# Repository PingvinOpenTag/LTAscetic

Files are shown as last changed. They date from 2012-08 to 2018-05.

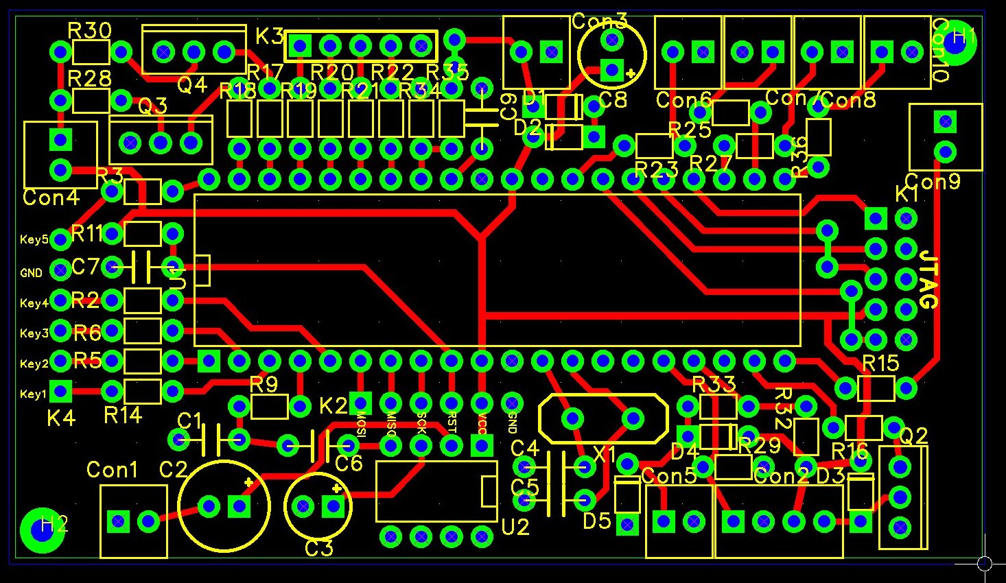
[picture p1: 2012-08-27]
release_2(LCD,Joystck,TouchMemory,Reload,Antichiter,IrPowerControl,BattaryControl)/hardware/pcb/layout.jpeg

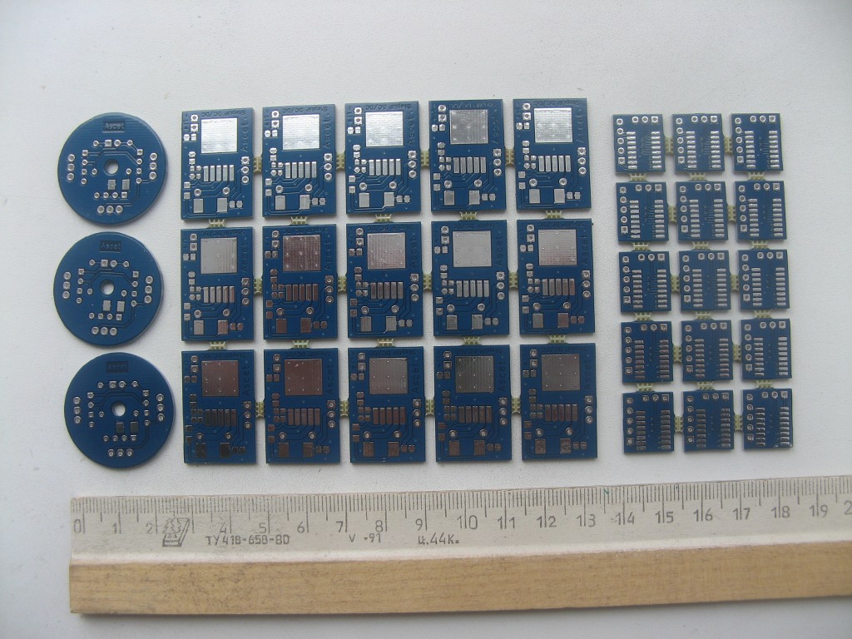
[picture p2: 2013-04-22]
release_3_1(SMD,fix_flesh_led_bag,firmware_up_to_56000Hz_IR_F0)/hardware/pcb/ir_sensor&step_up_dcdc&rs232_modul_pcb.jpeg

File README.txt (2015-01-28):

This is an open lasertag project.

In the directory "source" is the firmware source code
Copy the directory "/source/LTAscetic_Atmega32" on hard disk.
Open the file "X:/LTAsceric_Atmega32/LTAscetic_Atmega32.aps" in the program "AVR-Studio 4.16" (or 4.17, 4.18)
Сan work! :-)

!!!DO NOT USE 4.19 VERSION!!!

Just need to install the compiller WinAVR.

Program to configure the "Ascetic" and upload sounds.

http://sourceforge.net/projects/ascetconfigurat/files/Ascet-configurator/01_2013/

NEW!!!

http://sourceforge.net/projects/ascetconfigurat/files/Ascet-configurator/Qt5_version/02_10_2014/Configurator_and_libs_10_sounds.zip/download

Android port (Qt version)
http://sourceforge.net/projects/ascetconfigurat/files/Ascet-configurator/Qt5_Android_version/

PonyProg
serial device programmer

http://www.lancos.com/prog.html

PC software to use bootloader

http://download.chip45.com/chip45boot2_GUI_V1.13.zip

Part list for de.mouser (Use at your own Risk and please check !)

LTA Motherboard (3.1)
http://www.mouser.com/ProjectManager/ProjectDetail.aspx?AccessID=8740157a16

LTA Ir Sensor (3.1)

http://www.mouser.com/ProjectManager/ProjectDetail.aspx?AccessID=37c73c7856

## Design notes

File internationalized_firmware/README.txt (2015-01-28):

In the directory "source" is the firmware source code
Copy the directory "/source/" on hard disk.
Open the file "X:/source/LTAscetic_Atmega32.aps" in the program "AVR-Studio 4.16" (or 4.17, 4.18)
Сan work! :-)

!!!DO NOT USE 4.19 VERSION!!!

Just need to install the compiller WinAVR.

To compile the firmware with support for English, in the file ltag_ascetic.h define the macro LANGUAGE as follows:
#define LANGUAGE EN

if you want the message on the screen LСD and parameter names were in Russian, define the macro LANGUAGE as follows:

#define LANGUAGE RU

Program to configure the "Ascetic" and upload sounds.

http://sourceforge.net/projects/ascetconfigurat/files/Ascet-configurator/01_2013/

NEW!!!

http://sourceforge.net/projects/ascetconfigurat/files/Ascet-configurator/Qt5_version/02_10_2014/Configurator_and_libs_10_sounds.zip/download

PonyProg
serial device programmer

http://www.lancos.com/prog.html

PC software to use bootloader

http://download.chip45.com/chip45boot2_GUI_V1.13.zip

Part list for de.mouser (Use at your own Risk and please check !)

LTA Motherboard (3.1)
http://www.mouser.com/ProjectManager/ProjectDetail.aspx?AccessID=8740157a16

LTA Ir Sensor (3.1)

http://www.mouser.com/ProjectManager/ProjectDetail.aspx?AccessID=37c73c7856

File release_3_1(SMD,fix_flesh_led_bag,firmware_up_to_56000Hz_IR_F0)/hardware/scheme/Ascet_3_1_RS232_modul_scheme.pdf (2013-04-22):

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

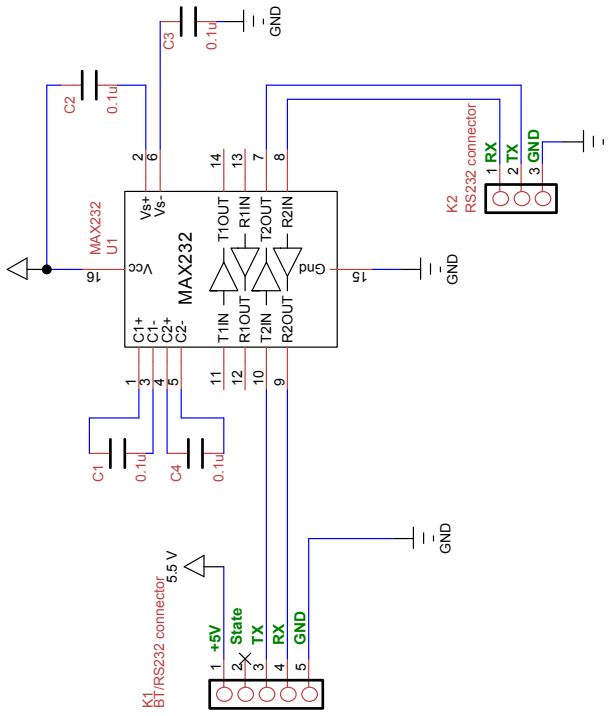
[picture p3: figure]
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

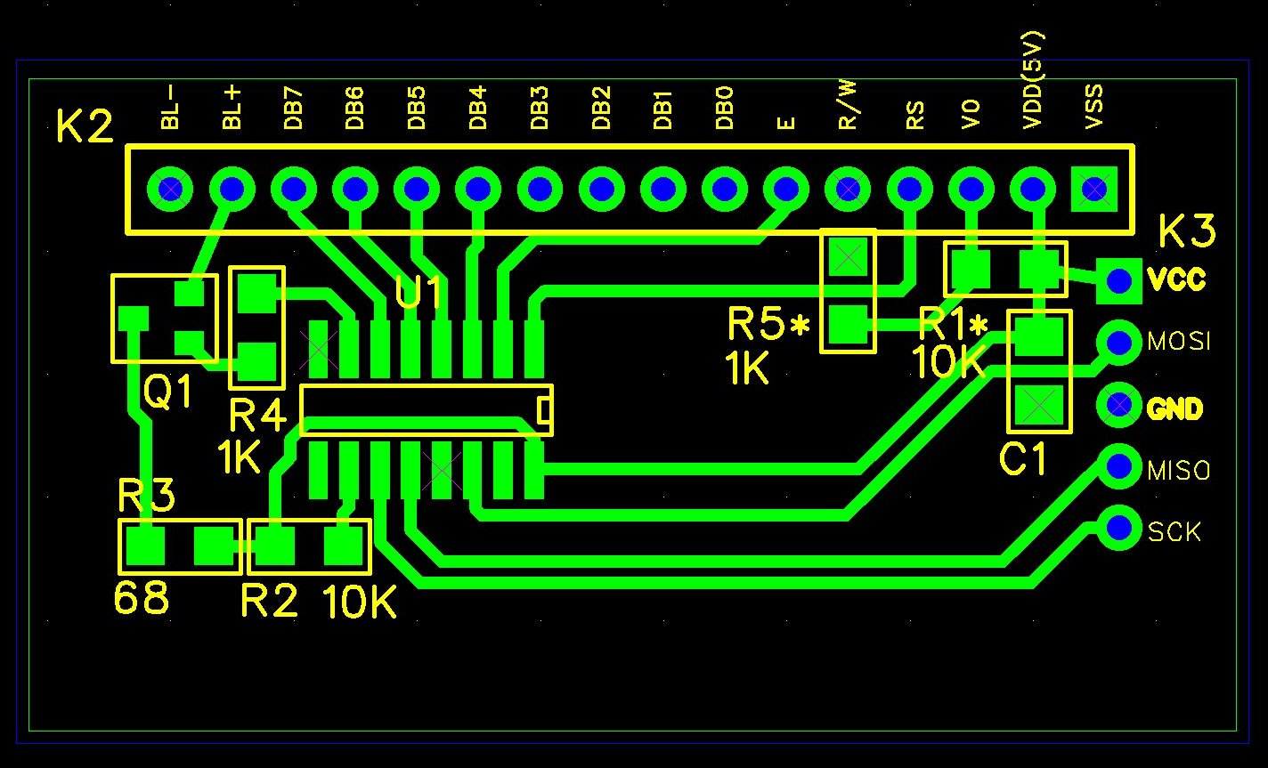
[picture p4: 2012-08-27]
release_2(LCD,Joystck,TouchMemory,Reload,Antichiter,IrPowerControl,BattaryControl)/hardware/pcb/lcd_shield_smd_layout.jpeg

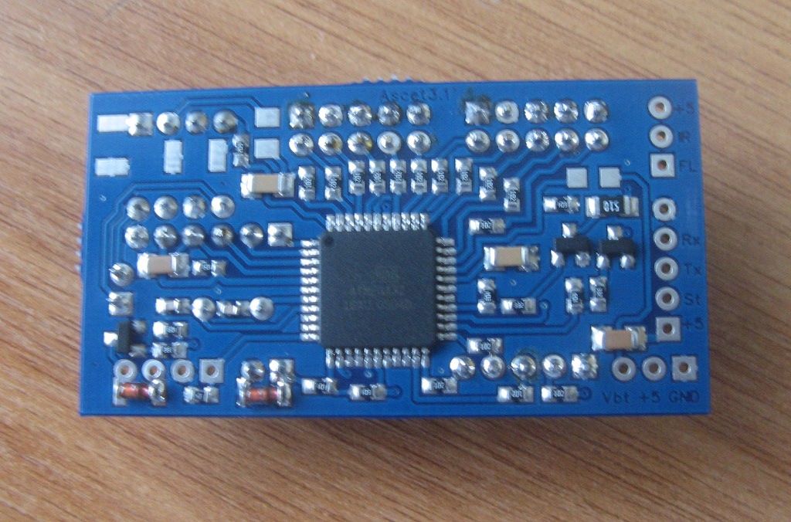
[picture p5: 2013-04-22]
release_3_1(SMD,fix_flesh_led_bag,firmware_up_to_56000Hz_IR_F0)/hardware/ascet_3_1_top.jpeg

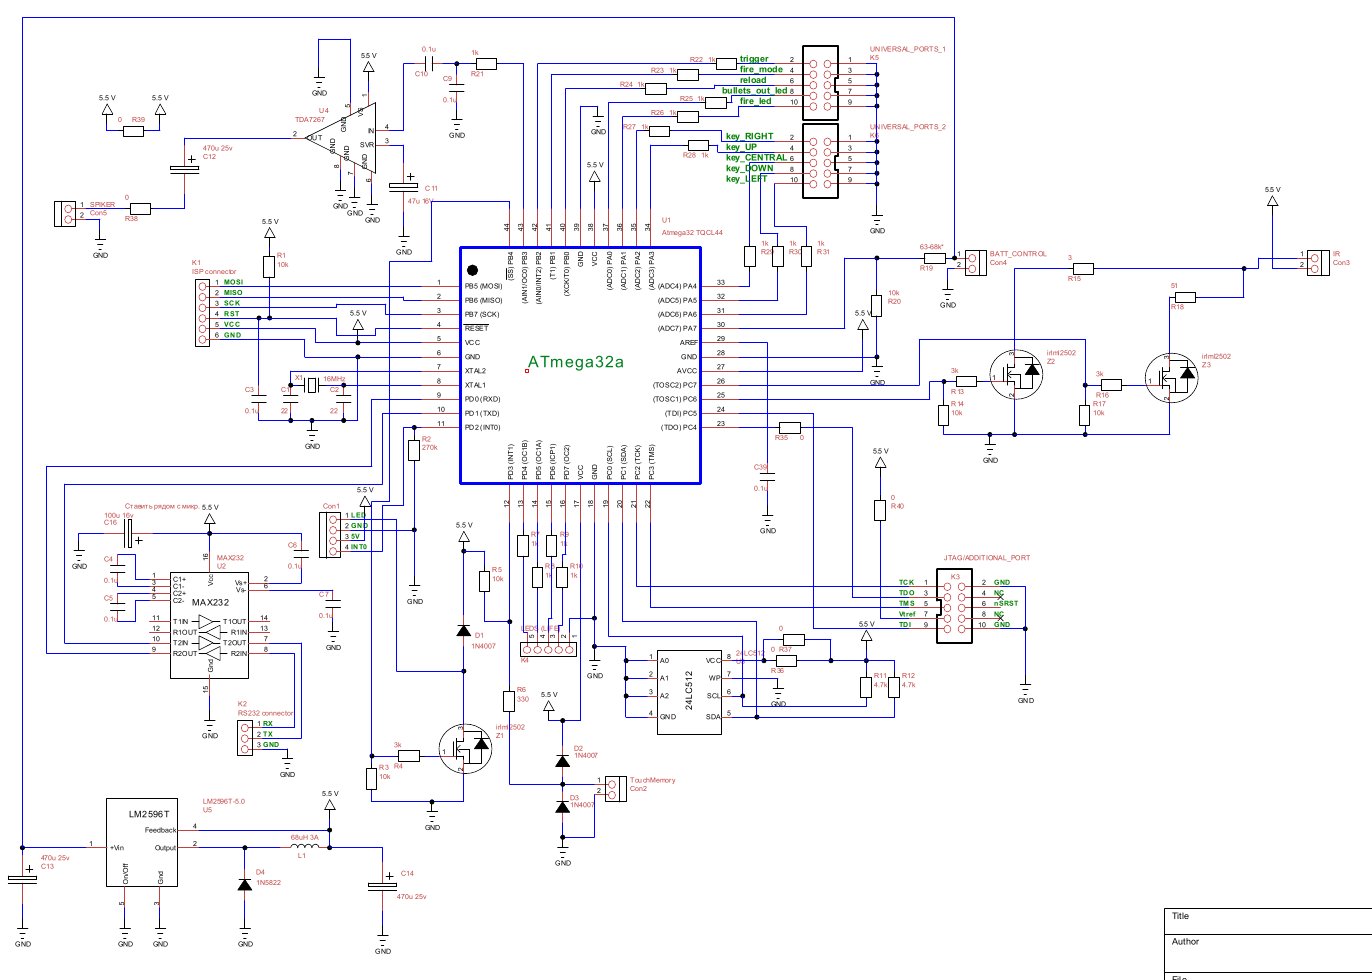
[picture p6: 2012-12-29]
release_3(all_thet_is_in_the_release_2,extern_EEPROM_RS232_BOOTLOADER)/hardware/scheme/Ascetic_3_scheme.jpg

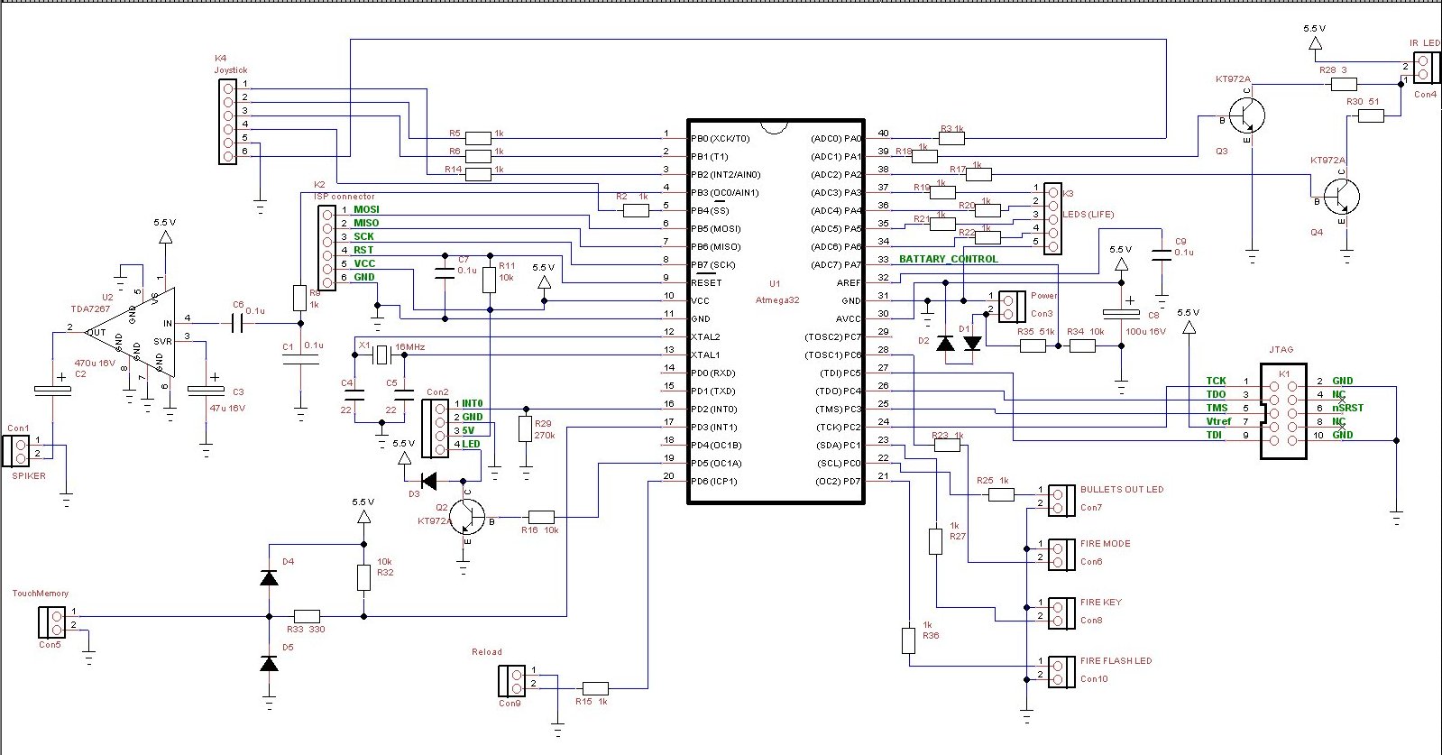
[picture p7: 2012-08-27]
release_2(LCD,Joystck,TouchMemory,Reload,Antichiter,IrPowerControl,BattaryControl)/hardware/scheme/scheme.jpeg

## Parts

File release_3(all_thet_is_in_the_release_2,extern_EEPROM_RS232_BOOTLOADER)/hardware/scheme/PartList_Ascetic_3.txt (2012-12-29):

====+  Parts List   +====

R35,R36,R37,R38,R39,R40       6   0,Resistor,1206
C16                           1   100u 16v,Electrolitic Capacitor
R1,R14,R17,R20,R5             5   10k,Resistor,0603
R3                            1   10k,Resistor,1206
D1,D2,D3                      3   1N4007
D4                            1   1N5822
R21,R22,R23,R24,R25,R26,R27,
R28,R29,R30,R31              11   1k,Resistor,0603
R10,R7,R8,R9                  4   1k,Resistor,1206
U3                            1   24LC512,512 Кбит (64К x 8) SEEPROM, I2C 400 КГц, 2.5- 5.5 V, SOIC-8
R2                            1   270k,Resistor,1206
R15                           1   3,Resistor,1206
R6                            1   330,Resistor,1206
R13,R16                       2   3k,Resistor,0603
R4                            1   3k,Resistor,1206
R11,R12                       2   4.7k,Resistor,1206
C12,C13,C14                   3   470u 25v,Electrolitic Capacitor
C11                           1   47u 16V,Electrolitic Capacitor
R18                           1   51,Resistor,1206
R19                           1   63-68k*,Resistor,1206
U1                            1   Atmega32,TQFP44
Con4                          1   BATT_CONTROL,New symbol,Conn2
C3,C39,C4,C5,C6,C7,C9,C10     8   0.1u,Ceramic Capacitor,1206
C1,C2                         2   22,Ceramic Capacitor,1206
K1,                           1   PLS-40 (6 pin), 2,54мм
K3,K5,K6                      3   PLD80 (2x5 pin), 2.54мм
L1                            1   68uH 3A,INDUCTOR
K4                            1   PLS-40 (5 pin), 2,54мм
U5                            1   LM2596T-5.0,Step-Down DC/DC convertor 5V 3A, TO-220-5
U2                            1   MAX232,Dual Full-Duplex RS232 Transceiver,SOIC-16
K2                            1   PLS-40 (3 pin), 2,54мм
U4                            1   TDA7267,DIP8
X1                            1   16MHz,Crystal Oscillator,
Z1,Z2,Z3                      3   irlml2502,SOT23
Con2,Con3,Con4,Con5           4   DG308-2.5-02P-14-00A(H)
Con1                          1   2xDG308-2.5-02P-14-00A(H)

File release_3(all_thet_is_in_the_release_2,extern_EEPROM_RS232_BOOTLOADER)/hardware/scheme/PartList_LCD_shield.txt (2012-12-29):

====+  Parts List for LTAscetic\release_3(all_thet_is_in_the_release_2,extern_EEPROM_RS232_BOOTLOADER)\hardware\scheme\TinyCAD_files\LCD_SMD_SHIELD.dsn  +====

R3                            1   68,Resistor,1206
R5*,R4                        2   1.1k,Resistor,1206
R1*,R2                        2   10k,Resistor,1206
U1                            1   74HC595D,S016
Q1                            1   BC847C,SOT-23
C1                            1   0.1u,Ceramic Capacitor,1206
K3                            1   PLS-40 (5 pin), 2,54мм
K2                            1   PLS-40 (16 pin), 2,54мм

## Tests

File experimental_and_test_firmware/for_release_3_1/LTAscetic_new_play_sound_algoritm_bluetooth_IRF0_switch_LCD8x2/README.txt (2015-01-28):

In this version of the firmware, there are important changes and additions.

Firmware can work with both wired bandanna, so it is with wireless Bluetooth bandana, and at the same time with two bandanas (bluetooth and wired).
Anticheat controls both zones, therefore,

IMPORTANT !!!
If you plan to use only wired bandanna, it is necessary to conclude pin STATE on the Bluetooth-connector to connect through a resistor 270K to ground.
Otherwise anticheat will not work correctly!
If you are difficult to solder a resistor, there is another way - correct file isr.с : in function ISR(TIMER1_COMPA_vect) {...} get the line to read

if ((! (TSOP_IN & TSOP_PIN)) && (! (BT_STATE_IN & BT_STATE_PIN))) // if the input INT0 low level and there is no Bluetooth connection

and correct it so

if ((! (TSOP_IN & TSOP_PIN)) / * && (! (BT_STATE_IN & BT_STATE_PIN)) * /) // if the input INT0 low level

Rebuild the project. 
The new firmware file with the extension .hex will be in a subdirectory "defalt" of the project directory.

Rewritten algorithm play audio files.
In this firmware sound files are reproduced through the interruption, and not in the main program loop.
Therefore, the main loop of the program keeps track of game events at the time, when you hear the sound.
Therefore, it became possible to process all the hits, that happened during playback  "injured sound".
But to give the player a chance to survive when he is being fired gunfire, put such a thing as "time invulnerability."
During this time, after the hit, the player invulnerable, all hit ignored.
Duration of invulnerability is adjustable from 0.5 seconds to 3 seconds.

In the settings now made and the carrier frequency of the IR signal - 36 or 56 kHz.

You can also adjust the rate when shooting in auto mode.

Firmware understands the IR RC command "Start Game" and "kill the player" and commands to change the colors of the team.
You can use the remote control "ascet-pult".
http://github.com/PingvinOpenTag/LTAscetic/tree/master/Ascet_pult_3_1
But before using it must be initialized after the firmware download.
Command to initialize on the menu.

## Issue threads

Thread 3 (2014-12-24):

Feature request: Englisch Translation

gamecompiler, 2014-12-24:
Hi, i and my friends use the LTAscetic project in Germany very much.
Its nice, and works well.
But the problem is, the LCD menu and the LTAscetic Configurator.
Only one in my team speaks the russian language.
Only he can use the Configurator.

This is a feature request(?): Please Translate the menu and the Configurator to English.

Thank you in Advance.

Tipp: I added a current regulator for the LED on the pcb to save power. Works well.

PingvinOpenTag, 2015-01-01:
Generating SSH keys
https://help.github.com/articles/generating-ssh-keys/
and send me the key.
I'll add it to the server, and you will have access, if I understand correctly the server.

 >> Your yadi.sk version or release 3_1 ?

Yes.

gamecompiler, 2015-01-01:
Oh, sorry my handy dont showed me the rest of the e-mail....
Id send it to your github e-mail -> ms_present_god@mail.ru
But i will resend it to your other e-mail.

gamecompiler, 2015-01-04:
Sorry, I have not started yet, I have huge headaches.
I'll get back to you if I feel good again.

Sorry.

gamecompiler, 2015-01-05:
Im back, id checked  insensitiveclod´s code on https://github.com/insensitiveclod/LTAscetic.
And i did not found any code difference.
It took me nearly 7 hours for the review....
The English Translation of his work is almost complete and has a good quality. Please put his code in the main repo if you also think his translation is ok.

insensitiveclod, 2015-01-07:
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

Wow:)

Such honor *bow*

The code compiles exactly the same as the version I used before
translation. It's only comments that got translated, prettified and a
bit streamlined.

I will pick up the work of making it 'even nicer' soon, by doing
code-cleanup a bit.
First i will look at the configurator + translation.

--
 Arnd

gamecompiler, 2015-01-07:
Awesome nice. I cant await to hear when you are ready. :)I currently try to find a translation trick for the Firmware which is better then global variables. Maybe we can store Kind of Language files in the EEPROM.(Sorry for those bad Spelling, German T9 in my mobile phone)-------- Originalnachricht --------Betreff: Re: [LTAscetic] Feature request: Englisch Translation (#3)Von: insensitiveclod An: PingvinOpenTag/LTAscetic Cc: Jason On 01/07/2015 02:00 PM, Pingvin wrote:
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

Wow:)

Such honor *bow*

The code compiles exactly the same as the version I used before
translation. It's only comments that got translated, prettified and a
bit streamlined.

I will pick up the work of making it 'even nicer' soon, by doing
code-cleanup a bit.
First i will look at the configurator + translation.

--
 Arnd

—Reply to this email directly or view it on GitHub.

PingvinOpenTag, 2015-01-07:
I can not add your ssh-key.
I do not know why, but there is an error.
Send it as an archive, try more.

gamecompiler, 2015-01-12:
Id see you added sth you call Anti-Cheat.
Who does this Anti-Cheat system work ?

Thanks in Advance.

PingvinOpenTag, 2015-01-13:
Anti-cheat does not allow the player to disconnect bandana during the game on or off Bluetooth bandanna.
That it can not be Duncan Macleod ;-)

gamecompiler, 2015-01-13:
I cant find the TDA7052 on Mouser as DIP.
We may need another Distributer for our parts.
Or we change the PCB, to let the SMD Version fit.

Or could i use a similiar IC ?
Id found the NJM386 IC.
Its similiar, has more features, we could change the volume over a gain pin.
And it has output power of 1 Watts.

http://www.mouser.com/ds/2/294/NJM386_E-232003.pdf

I would prefer to use mouser because mouser ships worldwide and is very cheap in conclusion to my known distributors.

PingvinOpenTag, 2015-01-16:
Began to correct the source firmware for multi-language support.
I use this method, in header file

#define EN 0
#define RU 1

#define LANGUAGE EN

in C file

#if LANGUAGE == RU
lcd_puts("Ключ ТМ");
#elif LANGUAGE == EN
lcd_puts("ТМ key");
#endif
lcd_gotoxy(0, 1);
#if LANGUAGE == RU
lcd_puts("записан!");
#elif LANGUAGE == EN
lcd_puts("recorded");
#endif

Teie, 2015-05-14:
Hi Pingvin, I'm Theuer from Brazil.
 GREAT JOB you made here!
I'm doing your project at protonboard, I tried open the ".c" files at maaaany softwares because my idea was to do "copy" Rusian COMMENTS and "paste" at Google Translator, but the comments not appears in Cyrillic. All comments appears like this: "//«‡ÔËÒ¸ ·‡ÈÚ‡ ‚ ÏÓ‰ÛÎ¸ Ô‡ÏˇÚË EEPROM"
 Do you know why?
 Others thing, I did not understand what it is for the EEPROM memory. Is it for Score? (Please say yes!) :)

 Sorry for terrible english, and congratulations for your hard work!
 See you, Theuer.

gamecompiler, 2015-05-15:
The Translation is already (almost) done, please try to read the issues first before you comment.
https://github.com/PingvinOpenTag/LTAscetic/tree/master/internationalized_firmware

Im not sure for what the EEPROM memory is for.
If i remember correct, it contains the playerid and settings like ammo, battery settings (Max and min values when the battery is full or empty e.t.c), health, damage rate....

If im correct there is no score feature, but if you like to add it, please feel free to share your code.

If you have more question, please feel free to ask ;D
Sorry for my english.

Teie, 2015-05-15:
I read the issues, but I had understood that the partial translation was in "internationalized_firmware" and when I opened, everything I saw was "//«‡ÔËÒ¸ ·‡ÈÚ‡ ‚ ÏÓ‰ÛÎ". Now I opened "intensitivecloud" and I found it all translated.

 Yes, my goal is to write score feature. My current system is MicroMT, and I'm dropping it because they lack the Score feature.
 My big question about ASCETIC was it can handle or not the Score feature, and today Pingvin answer:
 "Yes, of course - it is able to."
 Challenge accepted! :)

PingvinOpenTag, 2015-06-13:
GitHab why the substitute encoding. Try to download and unpack the archive. Yes, we have an internal controller eeprom little used. There's plenty of space to save the recorded hits.

Closed 2015-05-15.

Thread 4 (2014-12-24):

Pleases add a part list

gamecompiler, 2014-12-24:
Id made a part list for the LTAscetic 3.1 release.

Part list for de.mouser (Use at your own Risk and please check !)
If checked please add it to the Readme.md

LTA Motherboard (3.1)
http://www.mouser.com/ProjectManager/ProjectDetail.aspx?AccessID=8740157a16

LTA Ir Sensor	(3.1)

http://www.mouser.com/ProjectManager/ProjectDetail.aspx?AccessID=37c73c7856

PingvinOpenTag, 2015-01-05:
Ascet-configurator port from PC to Android
http://www.youtube.com/watch?v=n5ikXYz3mhE

Upload sounds use configurator on Android
http://www.youtube.com/watch?v=lW9ozMrs18M&feature=youtu.be

gamecompiler, 2015-01-05:
Could we use the NJM386 IC ?
Its avaible as DIP.
Or we use the SMD edition of the NJM386 IC.
You would need to change the pcb if we use the SMD edition.

What should we do ?

gamecompiler, 2015-01-13:
One Question, about the LCD-universal-Modul.
What data is owned by the Q1-BC847 and U1-MC74HC595AD (I only need the case type).
I will publish some more part lists if im ready.

Could you please send me a fix of the Bluetooth modul pcb DIPTrace_files ? I cant read the DIPTrace_files without problems. Part 1-2, i see something dont readable for me, my pc cant decode the russian language, i think.
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

Thanks in Advance

PingvinOpenTag, 2015-01-14:
And where do NJM386 IC?
It's a completely different chip, as I understand it.
Or it is a complete analog TDA7052A?

Сhange the pcb  can by anything, a matter of expediency.
I have no such need.

PingvinOpenTag, 2015-01-14:
BC847 has the same body as irlml2502  - SOT-23 (SMD).
74HC595D - SOIC-16 (SMD)

gamecompiler, 2015-01-14:
Id have problems ordering the Matherboard pcbs, could you export the gerber files as GBR files please ?

Freepcb wont let me do that.
Thanks in Advance.

PingvinOpenTag, 2015-01-14:
Complexity of translation.
I do not understand - from what program you want to export Gerber files?
And what of the PCB?

PingvinOpenTag, 2015-01-14:
I'd like to know more about your hardware.
Where to order the production of printed circuit boards?
Which configuration using ascetic?
Few photos, video ...
Could bring some joy to the old man?

gamecompiler, 2015-01-14:
Id ordered my pcbs at www.dirtypcbs.com.
They are not as dirty as id thought.
I will post pictures if id received them, and id built them.
Yes i could send some joy to the old man :).
But first i need to receive them.

I have following problems currently ordering the pcbs.

I need following types of data

Gerber file extension 	Layer
GTO 	Top Silkscreen (text)
GTS 	Top Soldermask (the 'green' stuff)
GTL 	Top Copper (conducting layer)
GBL 	Bottom Copper
GBS 	Bottom Soldermask
GBO 	Bottom Silkscreen
GML/GKO/GBR* 	Board Outline*
TXT 	Routing and Drill (the holes and slots)

First attempt was to convert the existing files to the needed files.
Id fail....

At this moment i redesign the Board in eagle; They also can use brd files.
The problem is that i will need to have this files in this night.
I think i will have a long night....

gamecompiler, 2015-01-14:
WARNING: Id found a lot of Erros, in the mouser part-liste.
Mouser did deledt some product pages, im not sure why....
Please DO NOT USE IT....
I need to fix that problems....
So many problems this night.... ARGH

gamecompiler, 2015-01-14:
Id redesigned the IR_Sensor in Eagle, i think this new design looks better.
And its a little bit cheaper to produce.
http://www.file-upload.net/download-10147101/export_IR_Sensor.zip.html

gamecompiler, 2015-01-15:
UPDATE: My new redesigned layout:
Do you think its ok ?
Sorry im under stress....

IR_SENSOR

http://dirtypcbs.com/order_images/13d093c9d5b35f3950eb14d471d986d7-4080_bottom.png
http://dirtypcbs.com/order_images/13d093c9d5b35f3950eb14d471d986d7-4080_top.png

LCD_UNI....

http://dirtypcbs.com/order_images/13d093c9d5b35f3950eb14d471d986d7-4081_bottom.png
http://dirtypcbs.com/order_images/13d093c9d5b35f3950eb14d471d986d7-4081_top.png

PingvinOpenTag, 2015-01-15:
FreePCB perfectly formed Gerber files!
Only for some reason he gives them another extension.
Do not worry, you can rename.
Gerber files are in the repository.
I did not do the Silks only
I did not do the inscriptions only Copper, Soldermask, Board Outline, Drill layers.

PingvinOpenTag, 2015-01-15:
What you do not like my version of the LCD module?
http://raw.githubusercontent.com/PingvinOpenTag/LTAscetic/master/release_2%28LCD,Joystck,TouchMemory,Reload,Antichiter,IrPowerControl,BattaryControl%29/hardware/pcb/lcd_shield_smd_layout.jpeg

PingvinOpenTag, 2015-01-15:
Blame !!!
Gerber files LCD module is not in the repository 2 release!
I mast to fix it!

I have Gerber files on all PCB that are laid out in the repository!

PingvinOpenTag, 2015-01-15:
GERBER for LCD module release 2.
https://yadi.sk/d/NVg_-IIMdykhL

PingvinOpenTag, 2015-01-15:
Why do you have such thin tracks on the boards?

gamecompiler, 2015-01-15:
Thanks for your gerber Files.
And a HUGE thanks for the tipp to rename the files.
I will try it out now.
I like your LCD_Shield Design ! But id thought i have to redesign everything in eagle.
Id also started last night to redesign the Matherboard in eagle.
I like more my IR_Sensor Design. I think it will be easier to wire to the head and shoulders.

Why such thin tracks ?; I do not know, id thought it will be enough thick. There is no really reason why id maked it as thin as it is.

gamecompiler, 2015-01-15:
Worked. Thank you !
Suuuch much thanks !

Cant await when they become shipped ;D

PingvinOpenTag, 2015-01-15:
So you do not have workers pay an "Аscetic"?
But you wrote that using them together with your friends!
What I do not understand ...

gamecompiler, 2015-01-15:
Now i do not understand you.
But i think I know what you do not understand.

I let my pcbs produce by www.dirtypcbs.com.
I and my friends already use LTAscetic, but dirty built on Breadboards.
So id decided to produce everything as pcb.
Yes my friends pay money to me, i build the Lasertag weapons for them.

Im not sure what you did not understand. Sorry.
And what do you mean with workers ?
Workes pay an Ascetic ?!? Huh ?

Im a Student in the 11. class.
Just to say it. I do not own a company.

PingvinOpenTag, 2015-01-15:
It's all  translator!
"рабочая плата" (works PCB) not "заработная плата" (Wages)

I wrote verbatim "Так у Вас нет рабочих плат Аскета? "
And the correct translation would be
"So you do not have workers PCB an ascetic?"
Here's a lesson in linguistics turned out!

gamecompiler, 2015-01-15:
I think we should create a Scoring Utility for Android.
I think it would be awesome to see Scores on a huge TV Screen using a Android TV Settop-Box.

Could you share your Code of your Android-APP ?
And could you make a Documentary how the Bluetooth/Serial commands work (A list would be enough) ?

Could i add lives or ammo to somebody over Bluetooth ?
Could we add a gamemode type like Capture of the Hill or Capture the Flag ?
First the code should be cleaned up ! What happend with Intensitiveclod ?
Is he/she already ready ? Did he/she already started ?

gamecompiler, 2015-01-15:
Part list updated

B45196H2476M309 is now knowed as T491C476M010AT.
That was the problem
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
gamecompiler, 2015-01-15:
Sorry, but i dont understand you

-->
Want, I will inquire the account on a partially assembled motherboard?
Can and sensors, but I ordered a kit, with collating chit will be more expensive, but Mogi and learn about them.
<--

PingvinOpenTag, 2015-01-15:
I can ask to me to issue an invoice for the production of printed circuit boards.
For comparison.

gamecompiler, 2015-01-15:
Ah ok. Thx, i think id understood you.
Can you give me access to your joomla site ?
I would start to write Documentary; how to use LTAscetic e.t.c.

PingvinOpenTag, 2015-01-15:
OK!
True, I still end up with a template is not defined.

Went to create a user.
Send your password by email.

PingvinOpenTag, 2015-01-15:
I sent a letter to check the mail.

gamecompiler, 2015-01-15:
Thanks.Could you please put the Joomla GUI into english ?I cant read everything Oo-------- Originalnachricht --------Betreff: Re: [LTAscetic] Pleases add a part list (#4)Von: Pingvin An: PingvinOpenTag/LTAscetic Cc: Jason I sent a letter to check the mail.

—Reply to this email directly or view it on GitHub.

gamecompiler, 2015-01-15:
Soory works. Id changed my local browser language to russian to be able to read russian.
Works now

gamecompiler, 2015-01-20:
Id found sth wrong, LTAscetic Matherboard 3_1 pcb files.

C1-C2 has package C1206thermal but a C0603thermal footprint.

R2-R4 has package C1206thermal but a C0603thermal footprint.
R6-9 has package C1206thermal but a C0603thermal.
R10 - R12 has package C1206thermal but a C0603thermal footprint.
R21 has package C1206thermal but a C0603thermal.
R37 has package C1206thermal but a C0603thermal.

X1 has no package on pcb files, what package is needed ?

Z1-4 has no package on pcb files, what package is needed ?

C11 has no package on pcb files, what package is needed ?
C15 is this part correct ?
http://www.mouser.de/Search/ProductDetail.aspx?R=EEE-FK1A102Pvirtualkey66720000virtualkey667-EEE-FK1A102P
C16 has no package on pcb files, what package is needed ?
C28 has no package on pcb files, what package is needed ?
C33 has no package on pcb files, what package is needed ?

Thanks in Advance.

gamecompiler, 2015-01-20:
What do yo mean with that ?
Terminal for connecting the reader dongle TouchMemory («pill"), or other devices that use 1-wire interface.

For what do i need this TouchMemory ?

gamecompiler, 2015-01-20:
Sorry, id found ever info for the packages on your homepage.
The DIPTrace files should be changed to the correct packages !!!
This is very baffling !
And you have some russian language in your English article.

->U3 1 24LC512,512 Кбит (64К x 8) SEEPROM, I2C 400 КГц, 2.5- 5.5 V, SOIC-8

PingvinOpenTag, 2015-01-21:
What do yo mean with that ?
Terminal for connecting the reader dongle TouchMemory («pill"), or other devices that use 1-wire interface.

For what do i need this TouchMemory ?
---------------------------------------------------------------------------
That players could not start the game itself, but only the referee can start the game. Only the referee can change the settings tag.
But with the advent of remote and settings for Bluetooth is no longer relevant.

PingvinOpenTag, 2015-01-21:
The DIPTrace files should be changed to the correct packages !!!
This is very baffling !
-------------------------------------------
LTAscetic Matherboard 3_1 pcb is not done in DipTaсe, can you mean FreePCB?

gamecompiler, 2015-01-21:
Sorry, yes i mean freepcb.-------- Originalnachricht --------Betreff: Re: [LTAscetic] Pleases add a part list (#4)Von: Pingvin An: PingvinOpenTag/LTAscetic Cc: Jason The DIPTrace files should be changed to the correct packages !!!

This is very baffling !

LTAscetic Matherboard 3_1 pcb is not done in DipTaсe, can you mean FreePCB?

—Reply to this email directly or view it on GitHub.

gamecompiler, 2015-01-21:
How do i start a game ?-------- Originalnachricht --------Betreff: Re: [LTAscetic] Pleases add a part list (#4)Von: Pingvin An: PingvinOpenTag/LTAscetic Cc: Jason The DIPTrace files should be changed to the correct packages !!!

This is very baffling !

LTAscetic Matherboard 3_1 pcb is not done in DipTaсe, can you mean FreePCB?

—Reply to this email directly or view it on GitHub.

PingvinOpenTag, 2015-01-21:
How do i start a game ?
-------------------------------------------

If the key Touch Memory is not stored in memory, simply press "reload".
If recorded - Touch Memory key attaching to the reader.

Closed 2015-02-21.

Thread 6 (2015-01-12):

Lasertag introduction for Readme

gamecompiler, 2015-01-12:
Hi, id translated the following text.
http://www.contronik.net/cgi-bin/contronik.pl?site=laser_tag
I think its a good text.

I think its the perfect text for our Readme.
Please check for spelling mistake

-------Text Start----------

Lasertag, also known as Laser Game or Laserspiel, is a strategy and sports game that demands
on accuracy, responsiveness and endurance. Its similiar to paintball.
But you dont shot with paintballs. Your Enemy will be marked by a little infrared signal which will be
evaluated by a electric receiver.
This makes Lasertag absolute harmless as a contrast to paintball.
No one runs to get in danger, you wont become dirty and you wont become hit by high-speed flying color balls.
First and foremost Lasertag is about the fun, tactics and teamwork skills to the fore.
And its better to participate into a Lasertag game instead of pressing just the mouse button on the computer.

To play Lasertag, you need a Gamergear, named Tagger.
Taggers are not cheap, a Tagger cost an average of 500 to 750 Euro.
Therefore we offer you a complete Open-Source Lasertag Tagger design, LTAscetic.
All schematics, PCB layouts and software codes are completely free to use for
non-commercial purposes.

For playing at least two persons or more are required, each person has to wear a Tagger and a associated receiver.
The receivers are attached to the body of the player.
Either they are attached to the upper body, back and shoulder.
Anpther method is to carry the receiver as a headband on the head.
Therefore we have a Bluetooth receiver headband and a wired one, see Sourcecode.
In genereal, three receivers are placed on the body.
All recipients are electrically connected to each other with a cable or via Bluetooth to the Tagger.
The evaluation of a hit takes place on the electronics of the taggers.
LTAscetic also offers a Anticheat feature at this time in the 3.1 Experimental Release.

We cordially invite you to use our Project for non-commercial purposes.
Have fun !

Text is in other form originally located in German at http://www.contronik.net/cgi-bin/contronik.pl?site=laser_tag.

Text end----------------

One question, how can we mark Issues as solved ?!?

PingvinOpenTag, 2015-01-13:
All schematics, PCB layouts and software codes are completely free to use for
non-commercial purposes.
---------------------------------------------
How Come?
Let it be completely free license.
Including for commercial use.
What do you think?

gamecompiler, 2015-01-13:
I agree with you , it's probably better if the project is completely free to use , distributors are allowed to produce the project.

Id changed the text for Commercial license now.

-------Text Start----------

Lasertag, also known as Laser Game or Laserspiel, is a strategy and sports game that demands
on accuracy, responsiveness and endurance. Its similiar to paintball.
But you dont shot with paintballs. Your Enemy will be marked by a little infrared signal which will be
evaluated by a electric receiver.
This makes Lasertag absolute harmless as a contrast to paintball.
No one runs to get in danger, you wont become dirty and you wont become hit by high-speed flying color balls.
First and foremost Lasertag is about the fun, tactics and teamwork skills to the fore.
And its better to participate into a Lasertag game instead of pressing just the mouse button on the computer.

To play Lasertag, you need a Gamergear, named Tagger.
Taggers are not cheap, a Tagger cost an average of 500 to 750 Euro.
Therefore we offer you a complete Open-Source Lasertag Tagger design, LTAscetic.
All schematics, PCB layouts and software codes are completely free to use for
non- and commercial purposes.

For playing at least two persons or more are required, each person has to wear a Tagger and a associated receiver.
The receivers are attached to the body of the player.
Either they are attached to the upper body, back and shoulder.
Anpther method is to carry the receiver as a headband on the head.
Therefore we have a Bluetooth receiver headband and a wired one, see Sourcecode.
In genereal, three receivers are placed on the body.
All recipients are electrically connected to each other with a cable or via Bluetooth to the Tagger.
The evaluation of a hit takes place on the electronics of the taggers.
LTAscetic also offers a Anticheat feature at this time in the 3.1 Experimental Release.

We cordially invite you to use our Project for non- and commercial purposes.
Have fun !

Text is in other form originally located in German at http://www.contronik.net/cgi-bin/contronik.pl?site=laser_tag.

Text end----------------

PingvinOpenTag, 2015-01-14:
OK!

PingvinOpenTag, 2015-01-14:
Abusing his official position, I created a website on the corporate server of the company where I work.
armamd.ltascet.com
Multilingual website, is there and the German language. So you can prepare articles for publication on the website. And if you are familiar with joomla, I can give you administrator access.

gamecompiler, 2015-01-14:
Yes i now joomla a little bit.
I really would like to write articles for publication on your website.
But do you not thing that adminstrator access is a little bit to heavy ?
I will not abuse the rights, but joomla offers also a moderator user.
A moderator user can write and create pages.
I think that would be enough.

Thanks in Advance.

PingvinOpenTag, 2015-01-15:
I am ready to give you any rights you desire! ;-)

PingvinOpenTag, 2015-01-15:
Text is in other form originally located in German at http://www.contronik.net/cgi-bin/contronik.pl?site=laser_tag.
---------------------------------------------------
Excellent site!
And I do not know anything!
This is your project?

gamecompiler, 2015-01-15:
No it is not my Site.
Id first built this device on contronik.net.
It looks very cool, but the shoot range is kind of boring.
And there are no game types and so on.
After that id researched a little bit more and id found your Project.
Just to say it, your Project is very hard to find.
On my research id found LTAscetic on google search page 20 or so.

PingvinOpenTag, 2015-01-15:
It's all fucking translator!

In Russian, the word "плата" has two meanings - "печатная плата" (PCB) and  "плата за работу" (payment for work)!
I wrote verbatim " Так у Вас нет рабочих плат Аскета?"
And the correct translation would be
"So you do not have workers PCB an ascetic?"

"рабочая плата" (works PCB) and "заработная плата" (Wages)   Immersed completely different meaning!

Here's a lesson in linguistics Recipients! ;-)

Once again - the project is absolutely free!
If anyone can make money on it - very good!

gamecompiler, 2015-01-15:
Ah ok :)
Id thought you may be interessted what files id send dirtypcbs now.
I now produce your ir_sensor, because for no reason they wont read my brd files correct....

Here are the files.
http://www.file-upload.net/download-10149853/toproduce.zip.html

gamecompiler, 2015-01-15:
And here my dirtypcb Eagle 6 konfiguration, maybe somebody need it later.
http://www.file-upload.net/download-10149860/dirtypcb.dru.html

Closed 2015-02-21.

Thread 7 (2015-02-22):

Create a makefile ?

gamecompiler, 2015-02-22:
Hi,
I think a makefile would be great.
If im correct, the firmware is compiled by winAVR.
It would be easier to let a makefile do everything.
Then also Linux users could compile the firmware.
I think its easier to download winAVR than installing a specifed AVR Studio Version.
Under and above Windows 8 the older versions of AVR Studio are a huge problem.
If somebody read this and know who to use winAVR, i please to this person to create a makefile.

Thanks in Advance.

PingvinOpenTag, 2015-02-23:
Projects easily imported into 6 studio.
Well, I 'll look for that file

Воскресенье, 22 февраля 2015, 11:57 -08:00 от Jason <notifications@github.com>:
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

gamecompiler, 2016-01-02:
Done, worked.

Closed 2016-01-02.

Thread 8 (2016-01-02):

Part list, updated

gamecompiler, 2016-01-02:
Hi, im back.
Id updated the part list, i please you to check it.

http://www.mouser.com/ProjectManager/ProjectDetail.aspx?AccessID=4928c44ff5

Id added as replacement for the TDA7052, the SO-8 of the TDA7052 version.
Id got a new email address. So please don´t wonder if you get e-mails from xxxx@strongforce.de. (I have a website now Oo!)

I have a good source of optics now.
Google card box lenses with

Diameter: 25mm
Focal Length: 45mm

are perfectly for TSUS5202 Infrared Emitting Diodes (15 degree).

Thanks in advance.
Greetings from germany :smile:

PingvinOpenTag, 2016-01-14:
TDA7052AT/N2,118   - it's SO-8 case?
I use DIP case.

gamecompiler, 2016-01-15:
That should be no Problem because the footprint fits. Its just in Z-Axis smaller.

Closed 2016-08-05.

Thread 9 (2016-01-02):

Android Ascet-configurator Translation

gamecompiler, 2016-01-02:
Hi, id used the Ascet-configurator (Android) today.
Please please translate it in English Oo!
And some things are displayed wrong on my phone.

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

gamecompiler, 2016-01-02:
Id started the translation already, but what means:
Скрыть служебные поля
Считать настройки

And id translated the second tab as preferences, where im able to upload, download preferences to device. And the last one as remote, where i can enter commands (?).

gamecompiler, 2016-01-03:
What is the baudrate to talk to the weapon ?
I got a message "Ascet 3.1" and nothing more....

Thanks in advance

PingvinOpenTag, 2016-01-09:
Well, I'll transfer. Module using the remote control is not implemented.

To read the settings from a device in the "Protocol" ("Протокол") you have to press the button "Read from the device" ("Считать из устройства")
https://www.youtube.com/watch?v=n5ikXYz3mhE

PingvinOpenTag, 2016-01-09:
Can i configure if a bluetooth bandana is used (Master/Slave) ?
Do i have to configure if keys are used ?
--------------------------------------------------------------------
Bandana - Master
Tag - Slave
Bluetooth modules are configured using the AT-commands
armada.ltascet.com/images/hc-05.pdf
http://armada.ltascet.com/index.php/ru/tekhnologii-v-menu/asket/moduli-rasshireniya-dlya-asketa/blyutus-modul/nastrojka-bluetooth-modulej

PingvinOpenTag, 2016-01-10:
I recommend to the bandana printed circuit board powered from 3V. Then bluetooth shield is not needed.
http://www.youtube.com/watch?v=OKqPU76Skjw

PingvinOpenTag, 2016-01-10:
Configurator will rewrite on QML (change the interface). Qt widgets not useful on small screens of mobile devices.

gamecompiler, 2016-01-12:
Ok, now im confused, to get it run, what i have to do ? I have two setuped weapons.
Cant you add a config.h file where im able to define if a bluetooth module, LCD e.t.c is connected or not ?

I do not understand how i do change the firmware. Id hoped that im able to do that in the configurator....
I just want a gun with wired head sensor ....
I just want to play :cry:

(Did you check the new part list ? Can´t await to build more of two)

PingvinOpenTag, 2016-01-14:
Nothing needs to be configured. Everything works so. If you do not need the LCD or Bluetooth - simply do not connect them to the board.

If you want to play only with a wired bandana - through a resistor 10 to the connecting pin "Status"  (pin 2 on connector for Bluetooth Module) to the ground, otherwise the system will not work against cheating.

Initially firmware (or bootloader) can upload with the help of SPI programmer.
Be very careful with setting FUSES!!!

Programmers are different.
The easiest - it's  "LPT  5 wires"
http://armada.ltascet.com/index.php/ru/proshivka/kak-i-chem-proshit-asketa

I recommend using the USB programmers.
http://dvrobot.ru/var/cache/images/product/45/00/4500628ad509cd073e987c6ba312fd40-324.jpg
http://dvrobot.ru/237/213.html
The program is to work with this programmer.
http://yourdevice.net/proekty/avrdude-prog

Subject extensive, I recommend to you before programming device, available on the respective resources, how to program the AVR for SPI
And at first practice on the breadboard.
Because if you are, for example, incorrectly configured FUSE - programmer can no longer connect to the controller.

There resource project

There resource project
Help me to fill it with content.
What is your native language?
http://armada.ltascet.com

gamecompiler, 2016-01-14:
Ok, can you resend me the login details ?
My new e-mail address is justus (at) strongforce (DOT).de
my old still exists and i also read from this mail.

Thanks in advance.

PingvinOpenTag, 2016-01-16:
Check Mail

Closed 2016-08-05.

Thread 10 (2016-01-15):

Lense tube maker

gamecompiler, 2016-01-15:
Id found it useful to print Lense holder tubes.
Here is a OpenSCAD script.
[optic.zip](https://github.com/PingvinOpenTag/LTAscetic/files/92396/optic.zip)

If you wont install OpenSCAD. Use the thingiverse costumizer.
http://www.thingiverse.com/thing:1271102

PingvinOpenTag, 2016-01-17:
ОК

Closed 2016-01-15.

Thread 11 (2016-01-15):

Ideas for improvements

gamecompiler, 2016-01-15:
Hi, i would suggest us to do a COMPLETE rewrite of code and hardware.
I started my self a repo (i will delete in future, it was just a collection of my ideas).
And here is what id found out while playing Lasertag in a Arena, what would be cool in future, while developing sth new:

New Hardware assets and features:
- Ammo, Health and Life boxes, via RFID (Done at hardware side, only need to upload)
- Towers for Towerdefense, also via RFID (Done at hardware side, only need to upload)
- RFID Entry gate to register guns joining the game
- Targets which are RF connected and maybe trigger events
- DMX Devices (Done at hardware and software, eassily, useable over Serial Bus,)
- No Display required, manageable over PC-side software (Which is almost done, we need to try again to get me writing rights into repo)
- RF via NRF24L01
- Integrated LiPo loader and Fuel Gauge (Done, just need to upload, also with Tricky Infrared led circuit i will figure out later)
  - MCP73831 LiPo Battery Charger
  - MAX17048 LiPo Battery Fuel Gauge
- Tricky Infrared led circuit (see images in the end), to save power and needed parts.
- ws2812b connector ? Maybe funny for kids, to have lasertag like blinking guns
- Schematic in Eagle

Modes:
- Zombie (Id never understood how to play that Oo)
- Juggernaut
- Team
- FFA
- Tower defense
- Capture the Flag (RFID Flag)
- Shot em (Im sure this do not exist, i thaught a game mode where you have to shot targets faster than your "Enemy" would be col
  *... Do you know more ?

To get the pc side running i would like to have a NRF24L01 MASTER node using RF24 MESH library.
Here is a list of commands i would like to have (My pc side applications awaits this commands at this time)

```
--------------------------------------
--                                  --
--                                  --
--          __  COMMANDS __         --
--                                  --
--------------------------------------

---------------------
--  __Playername__ --
---------------------

/get playername device //Get playername which is currently assigned at device
/set playername device //Set a playername at device

---------------------
--  __Devices__ --
---------------------

/get device <device>//Get status of device, like a ping
/list device //List all device connected to master

---------------------
--  __Respawn and Life__ --
---------------------

/set respawntime <amount> [playername]  //Needed for every player to make Juggernaut and Kingofthehill more fair
/get respawntime [playername] //Get respawntime for playername

/set max life   <amount>    [playername]    //Set maximum of lifes, so that some people cant have 99 lifes because they know how to get extra lifes
/set start life <amount> [playername]   //Sets the amount of lifes the player will start

----------------
--  __Score__ --
----------------

Score is handled by PC-side

----------------
--  __Ammo__  --
----------------

/set start ammo <amount> [playername]//Sets the amount of ammo the player will start

/get ammo <playername> //Returns current ammo amount of playername
/set ammo <playername> <amount> //Sets playername ammo at amount

----------------
--  __Health__--
----------------

/set max health <amount>    [playername]    //Set maximum of health  [for playername]
/set start health <amount> [playername] //Sets the amount of health the player or all will start

/get health <playername> //Returns current health amount of playername
/set health <playername> <amount> //Sets playernames health at amount

----------------
--  __Team__ --
----------------

/get team <playername>  //Returns teamname of playername
/set team <playername> <teamname> //Sets playernames team to teamname
/list team  //Returns all teams and playernames assigned to teams

----------------
--  __Sound__ --
----------------

/set soundlevel [playername] [device] //Sets the sound level of device or playername

```

Here in the end are some chematics, first one design i did, still need to make a pdf of the complete lasertag design with Lipo charger and RFID reader. Currently i have uploading problems again....

https://github.com/gamecompiler/SKIRMTAG/blob/master/hardware/SKIRMTAG.pdf

Greetings from germany.
I would like to see LTAscetic to be as good as commercial Lasertag guns.

Ah, before if forget it, id made the Lasertag Lense Tube Configurator id made before ready to be run on a simple php website.

P.S the background is animated in the Highscore screen (Video loop used from dreamscene, called Moonview)
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

PingvinOpenTag, 2016-01-16:
Many of these you I want to realize the project "Armata".
Already 90% of the work done.
If you want to participate development project Armada - I'll give all the sources.

gamecompiler, 2016-01-16:
Ok, i swear i would not.
So if i participate in ARMada,
we have to talk over E-Mail.

I close this issue.
Would be awesome if my Software would run "almost" Out of the Box with ARMada.

Greetings from Germany,
gamecompiler.

PingvinOpenTag, 2016-01-16:
I am using a development environment CooCox.
http://www.coocox.org

Check your Mail?

gamecompiler, 2016-01-16:
I did check, at this time i did not receive a E-mail Oo. Im sorry.
But id found some errors in the forum,

[ul]
  [li]TEXT[/li]
  [li]Texst[/li]
[/ul]

Does not work.

PingvinOpenTag, 2016-01-16:
Did you not login and password, do not enter. I sent them to your е-mail.

gamecompiler, 2016-01-16:
? No im confused. I do not understand what you mean.

If you mean the login details for the forum e.t.c.
Im already in work, id received them already.

But i did not received the ARMada code if you mean that.

Am 16.01.2016 um 15:50 schrieb Pingvin:
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

PingvinOpenTag, 2016-01-16:
I see your message on the forum!
What does not work?

gamecompiler, 2016-01-16:
If i make a unsorted list.

[ul]
[li]TEXT[/li]
[li]Texst[/li]
[/ul]

The dots that should be visible do not appear.

gamecompiler, 2016-08-05:
Huge update !
Im sorry that i did not posted any updates a long time,
ive got many problems with my 3D printer, but now he works well.

Ive remixed dan0nator Halo Gun Design for lasertag.
Its now designed to fit 2 Lipo packs @ 2000mAh, a esp8266, the lense, rumble motor, and a piezo speaker (in future a better one).

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

Also almost ready is a IR sensor holder (Id damaged 7 of them cause of ESD.... So this is a resolution).
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

Files will be uploaded when they work 100%, i and a friend will check everything working on 8.8.2016.
Hope your are well ;D

What happend with the LTAscetic Homepage ?
Im able to login, but cant write any articles Oo!

With king regards,
gamecompiler

gamecompiler, 2016-08-06:
The password reset function does not work on http://armada.ltascet.com.
Anyway, here are again some updates of my ir sensor holder,
id made 3 more versions today. The new versions add cable holes to hide the cables.
Im not sure if its good to let the cables go out under the top. Maybe it would be better to let them go out on the sides. What do you think ? Where should the cables go out ?

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

gamecompiler, 2016-08-07:
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

PingvinOpenTag, 2016-08-08:
Cool!

PingvinOpenTag, 2016-08-08:
Send me an e-mail a new password, I will change

Closed 2018-01-20.

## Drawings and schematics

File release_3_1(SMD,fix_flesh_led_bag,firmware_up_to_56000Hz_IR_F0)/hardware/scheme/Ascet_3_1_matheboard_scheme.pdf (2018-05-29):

## trigger fire_mode

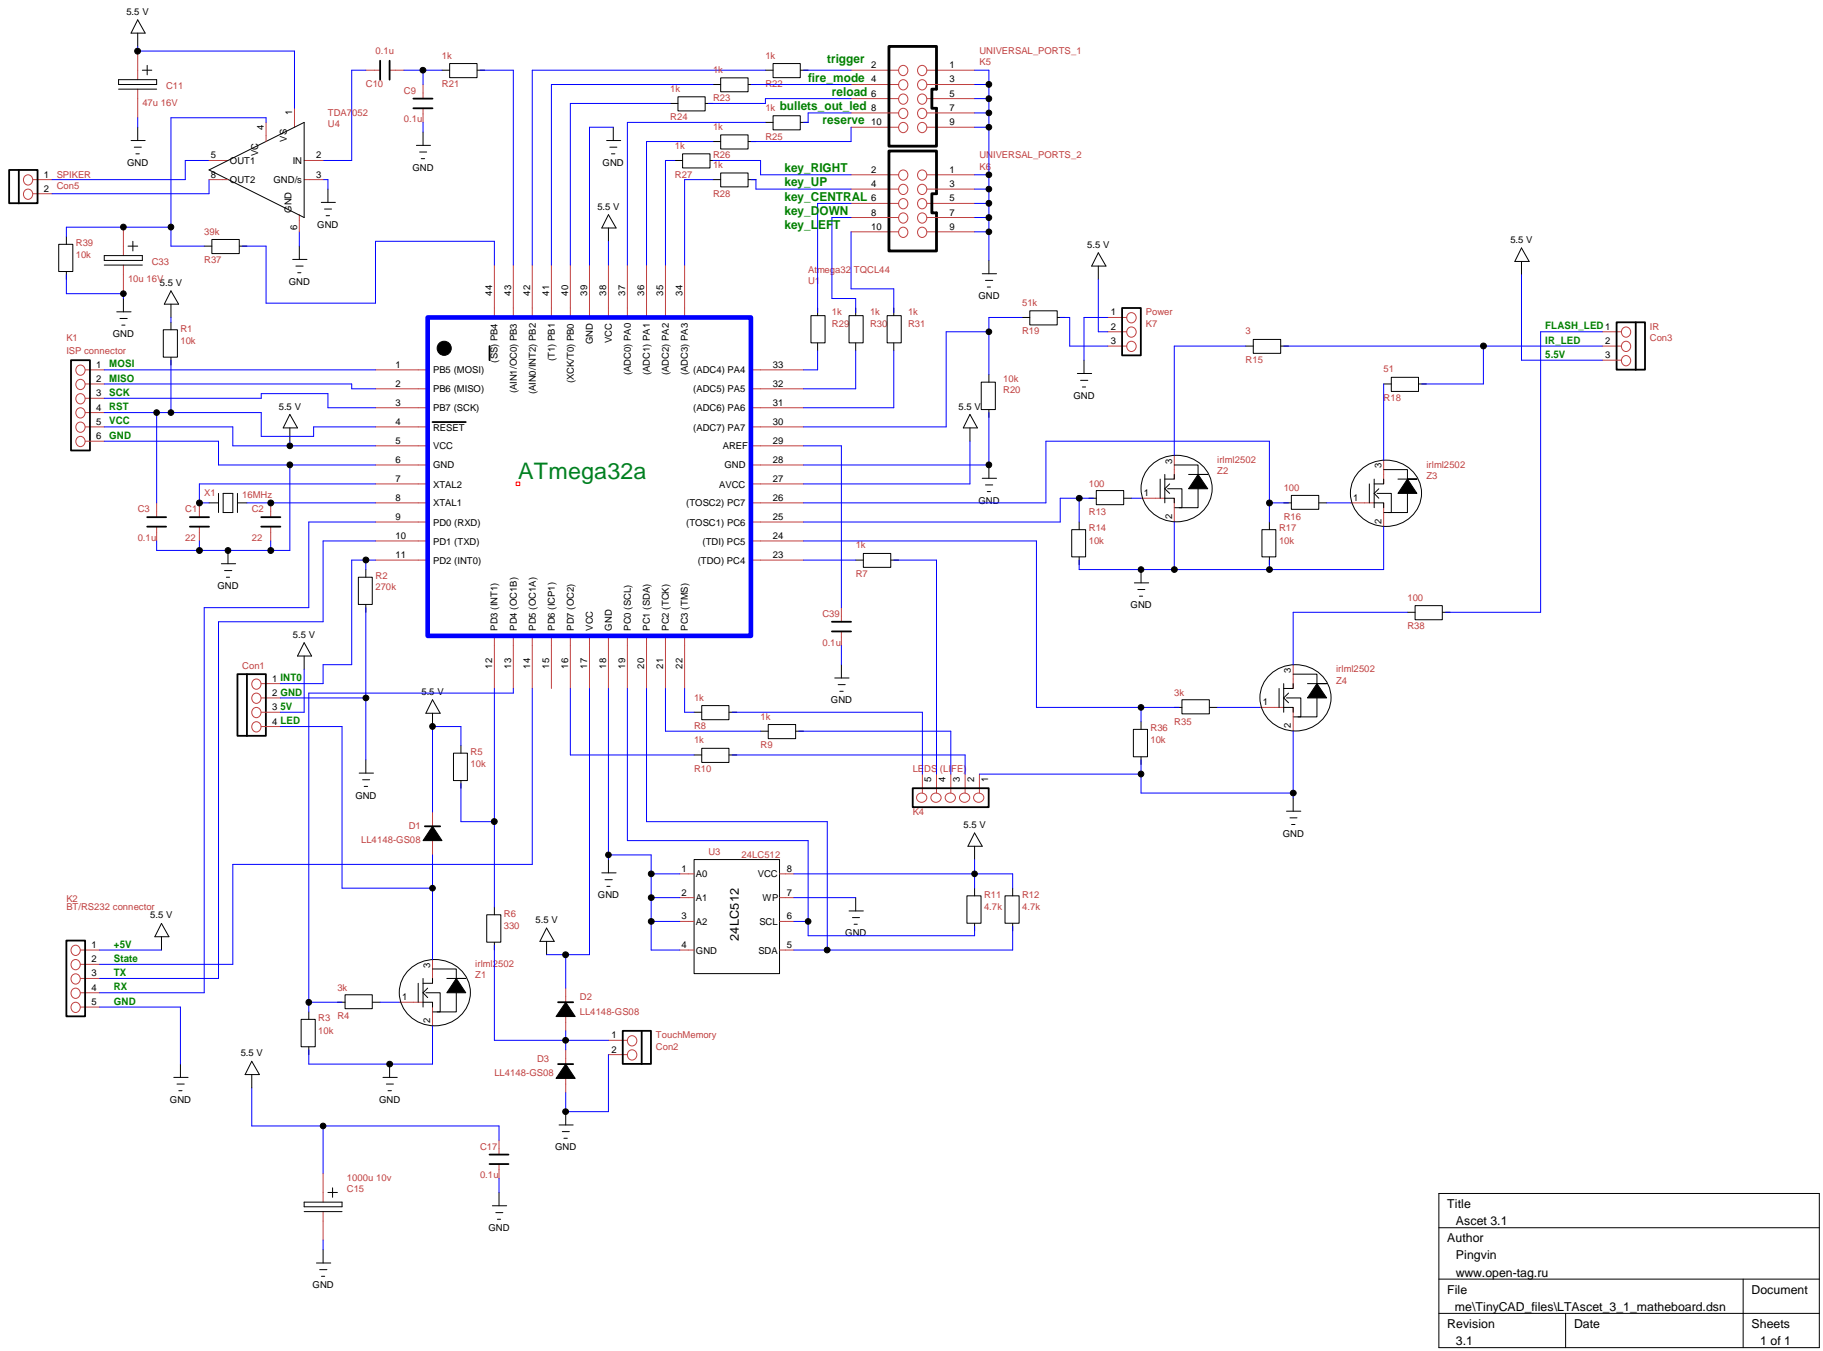
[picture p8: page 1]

File | Document

Revision 3.1 | Date | Sheets 1 of 1

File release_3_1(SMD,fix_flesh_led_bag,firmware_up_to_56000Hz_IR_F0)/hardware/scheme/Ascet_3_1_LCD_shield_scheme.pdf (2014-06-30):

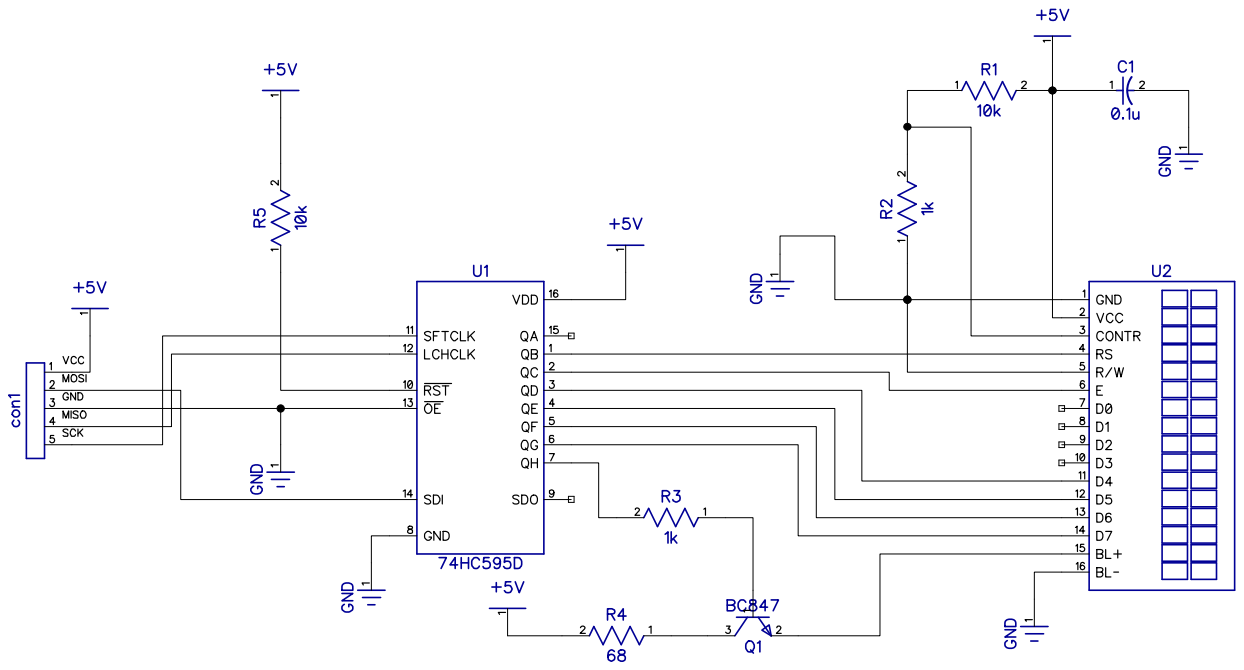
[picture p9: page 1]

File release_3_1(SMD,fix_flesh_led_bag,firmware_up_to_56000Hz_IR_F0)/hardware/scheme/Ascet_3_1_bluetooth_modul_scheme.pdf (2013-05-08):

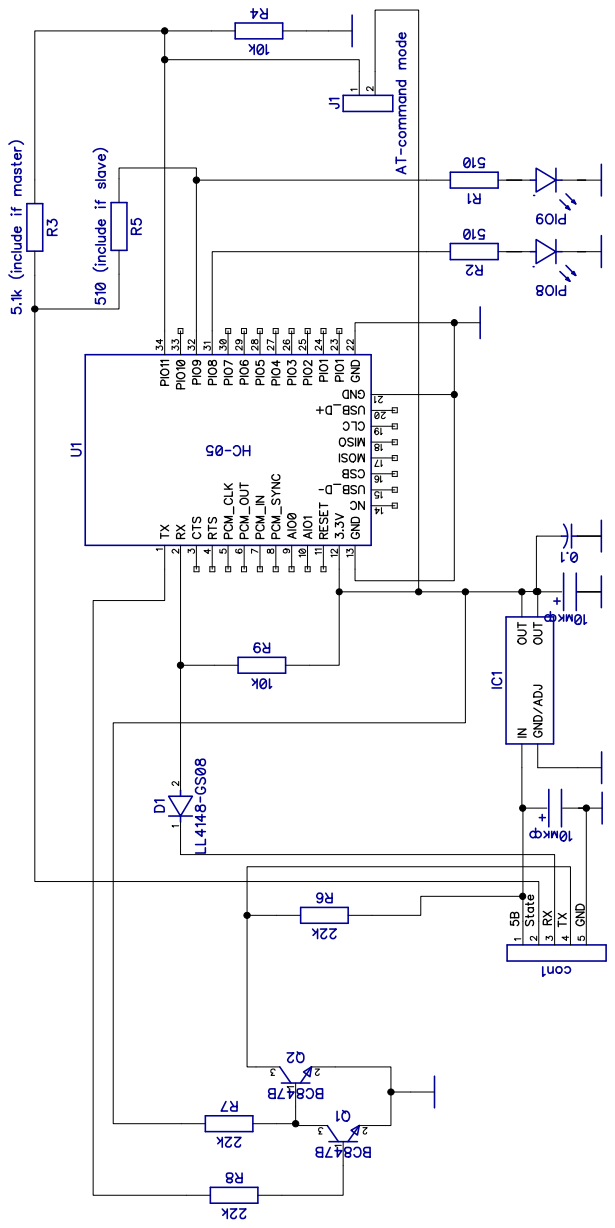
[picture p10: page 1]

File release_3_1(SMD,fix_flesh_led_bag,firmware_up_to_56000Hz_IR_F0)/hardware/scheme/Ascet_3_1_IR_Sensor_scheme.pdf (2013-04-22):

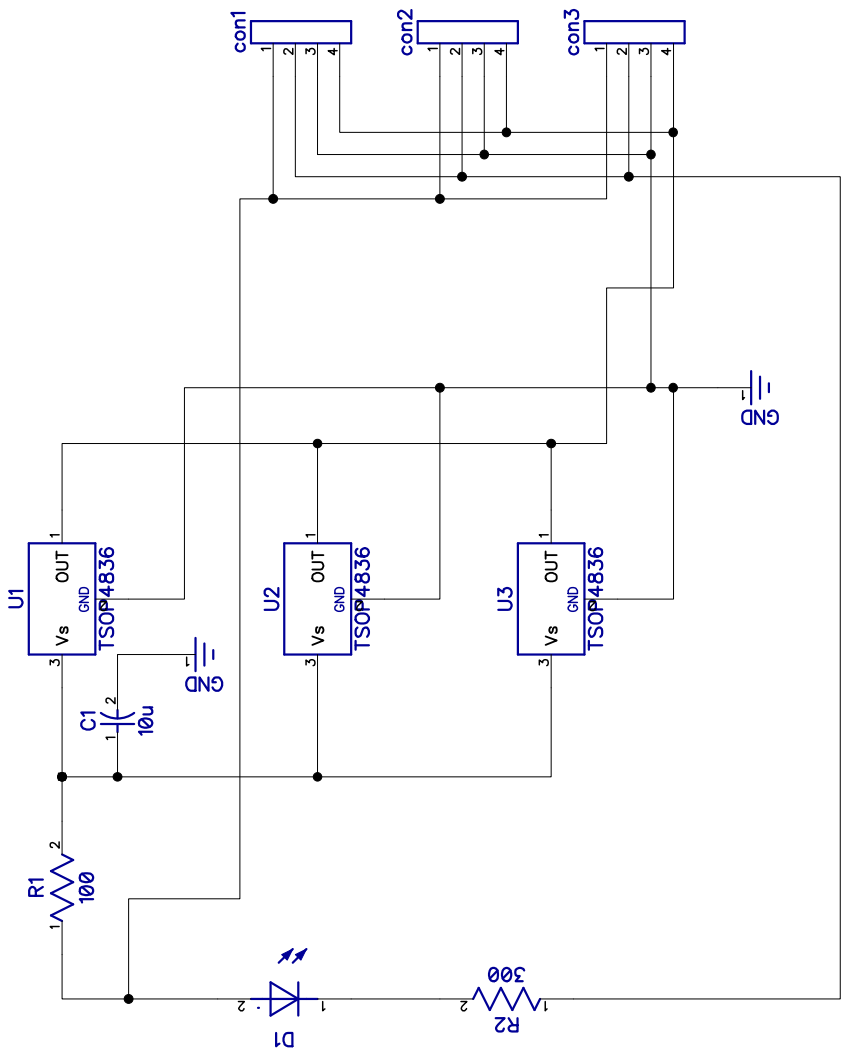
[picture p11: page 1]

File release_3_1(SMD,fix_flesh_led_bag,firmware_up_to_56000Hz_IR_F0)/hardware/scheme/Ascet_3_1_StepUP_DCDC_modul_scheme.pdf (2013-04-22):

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

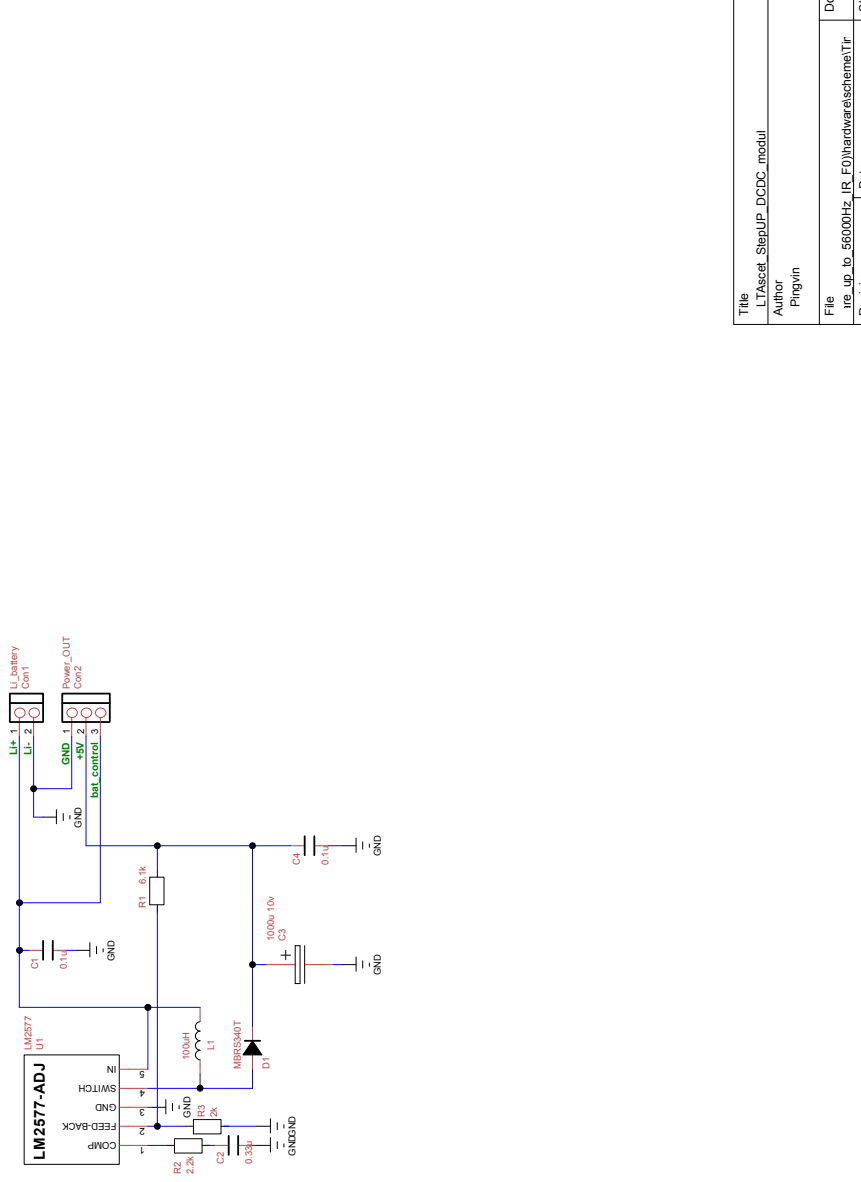
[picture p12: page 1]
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

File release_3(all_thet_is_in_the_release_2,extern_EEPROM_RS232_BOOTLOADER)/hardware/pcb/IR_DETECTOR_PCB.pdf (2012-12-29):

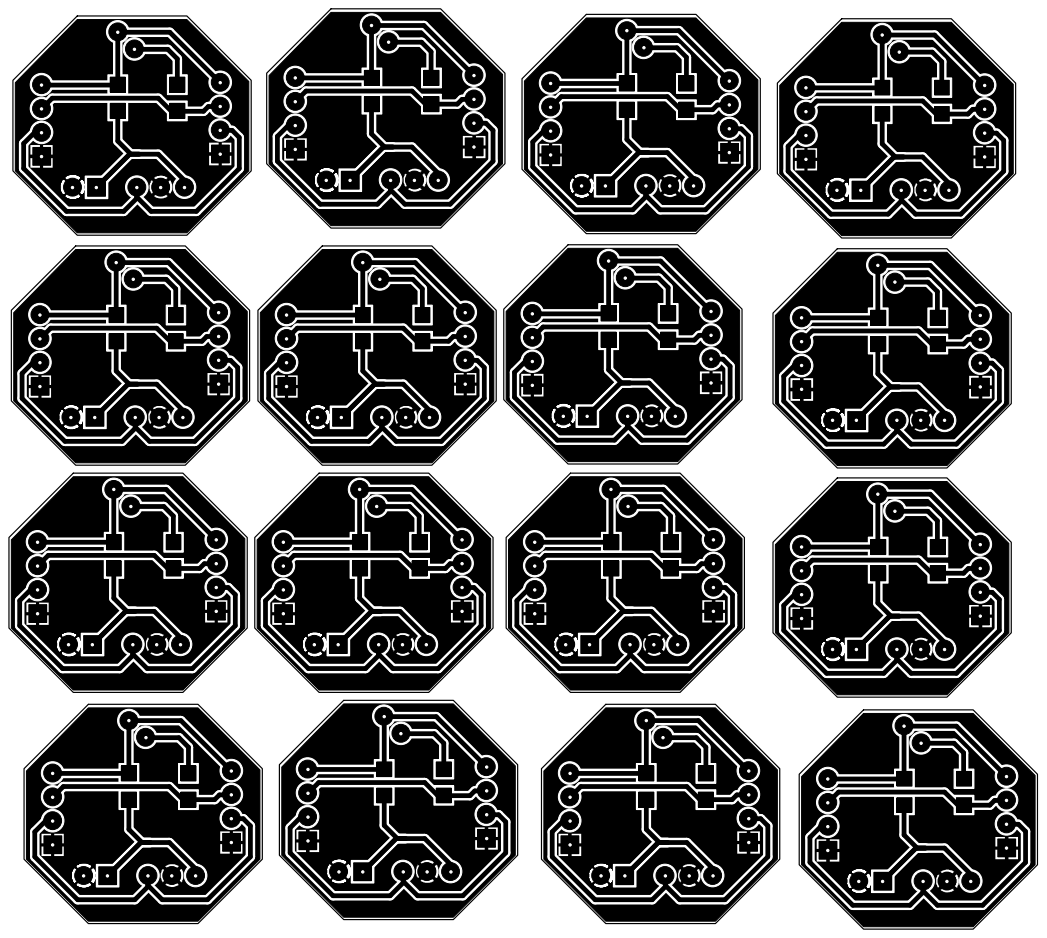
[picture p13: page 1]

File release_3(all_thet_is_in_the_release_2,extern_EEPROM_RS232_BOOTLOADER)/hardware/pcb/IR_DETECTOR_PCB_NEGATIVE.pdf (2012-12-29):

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

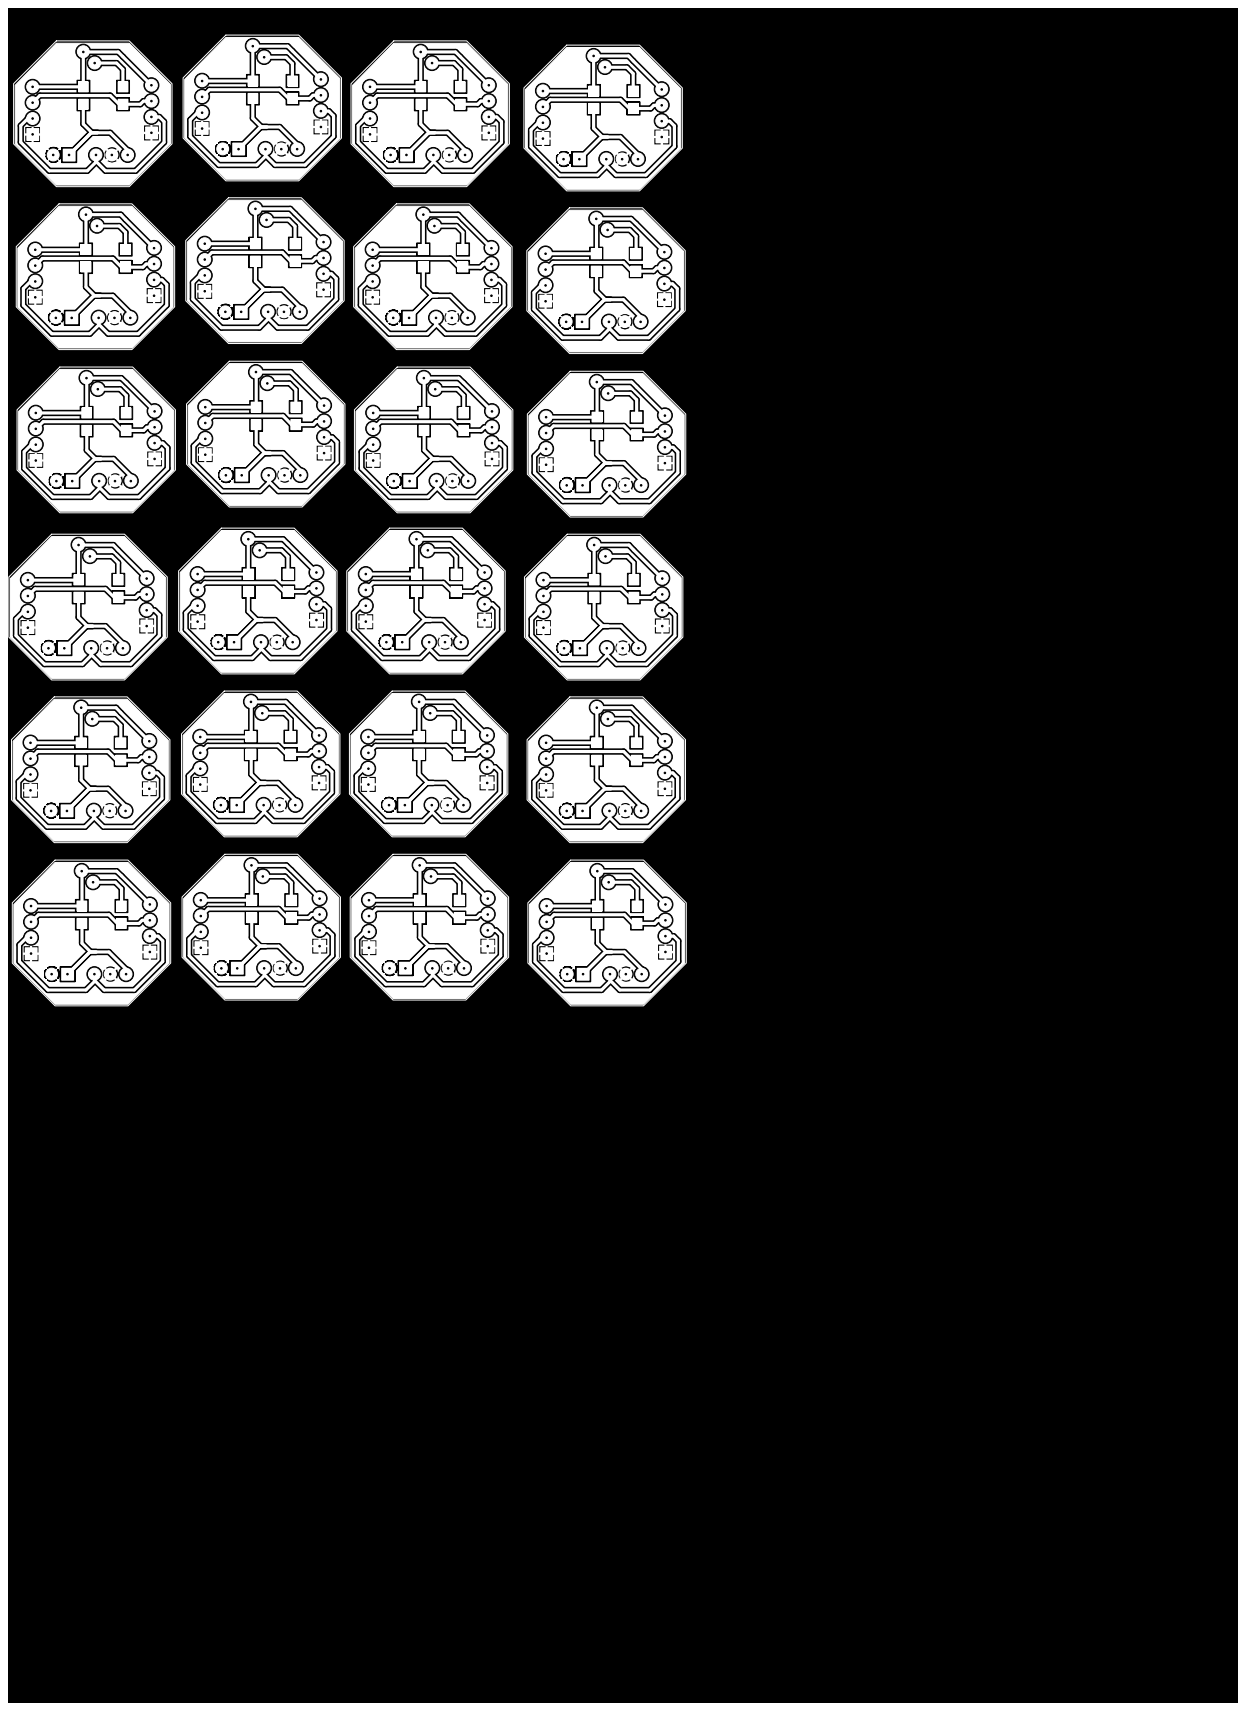
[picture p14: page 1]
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

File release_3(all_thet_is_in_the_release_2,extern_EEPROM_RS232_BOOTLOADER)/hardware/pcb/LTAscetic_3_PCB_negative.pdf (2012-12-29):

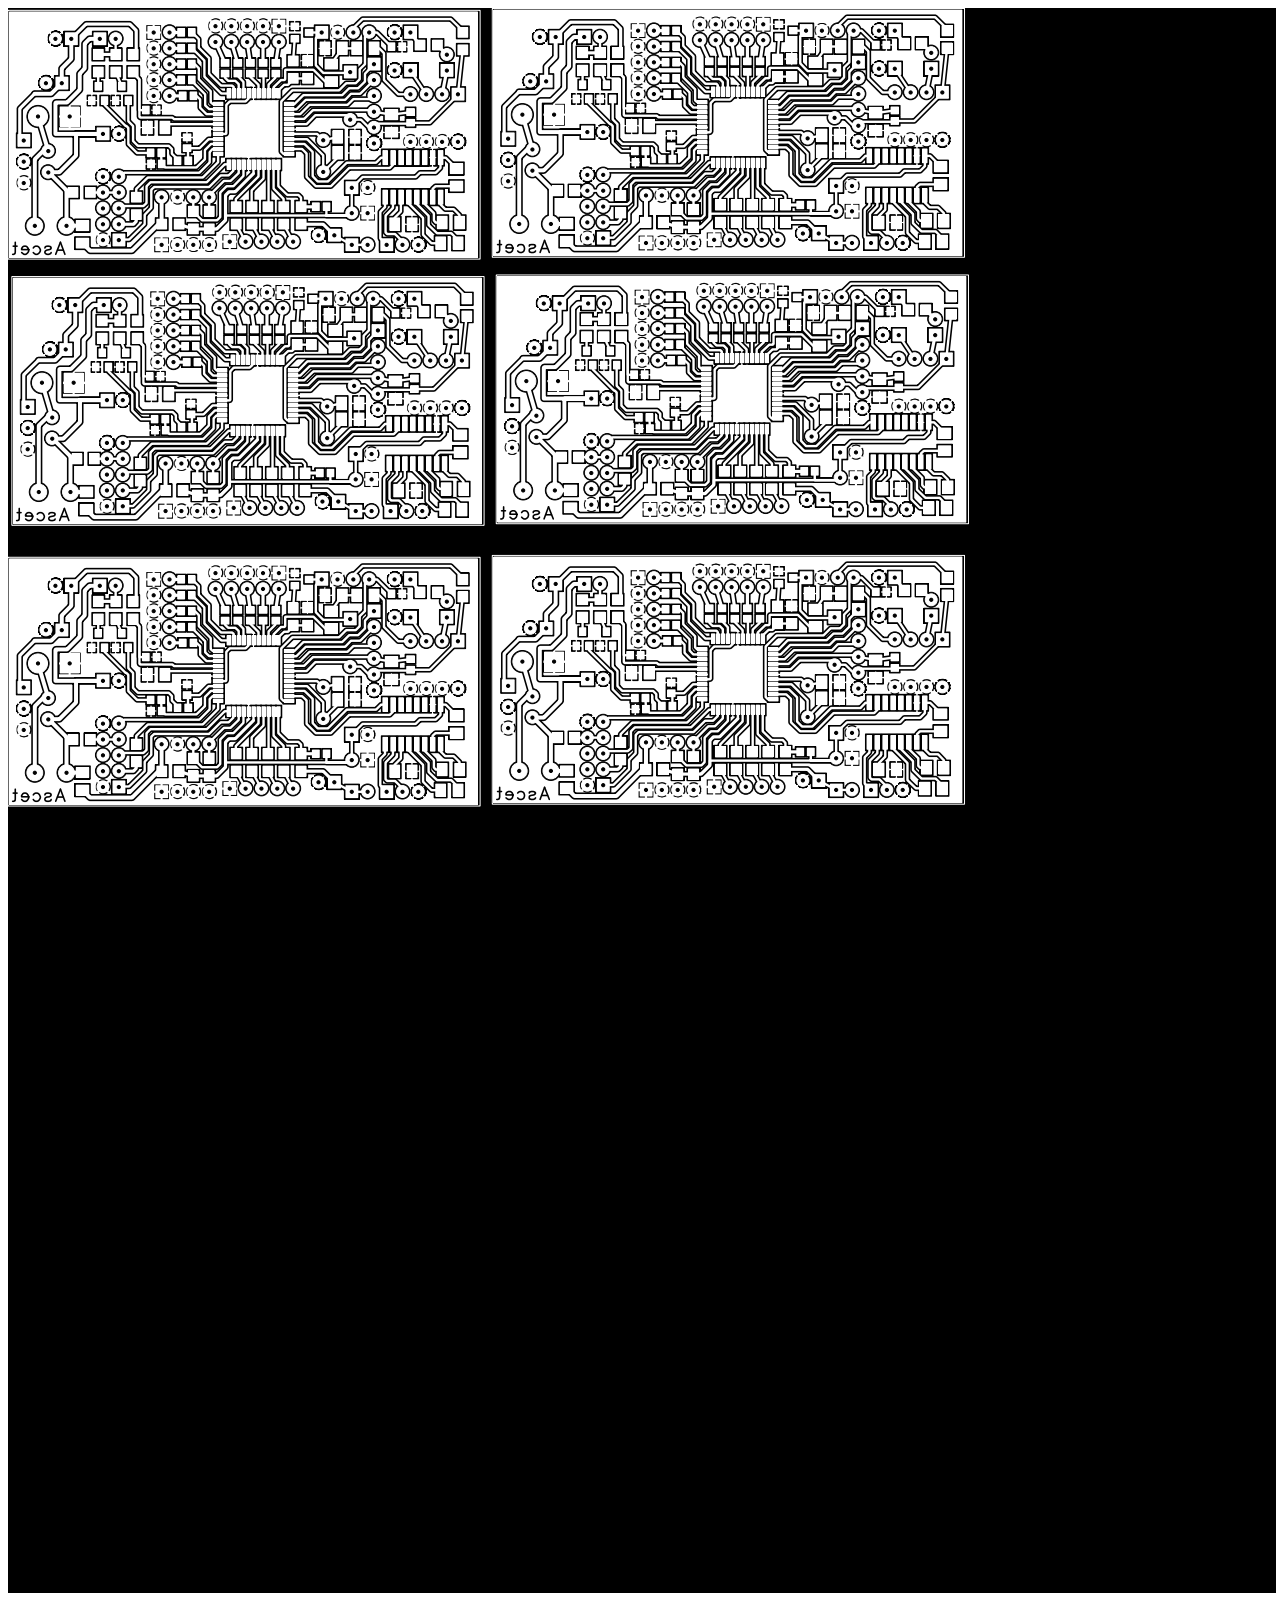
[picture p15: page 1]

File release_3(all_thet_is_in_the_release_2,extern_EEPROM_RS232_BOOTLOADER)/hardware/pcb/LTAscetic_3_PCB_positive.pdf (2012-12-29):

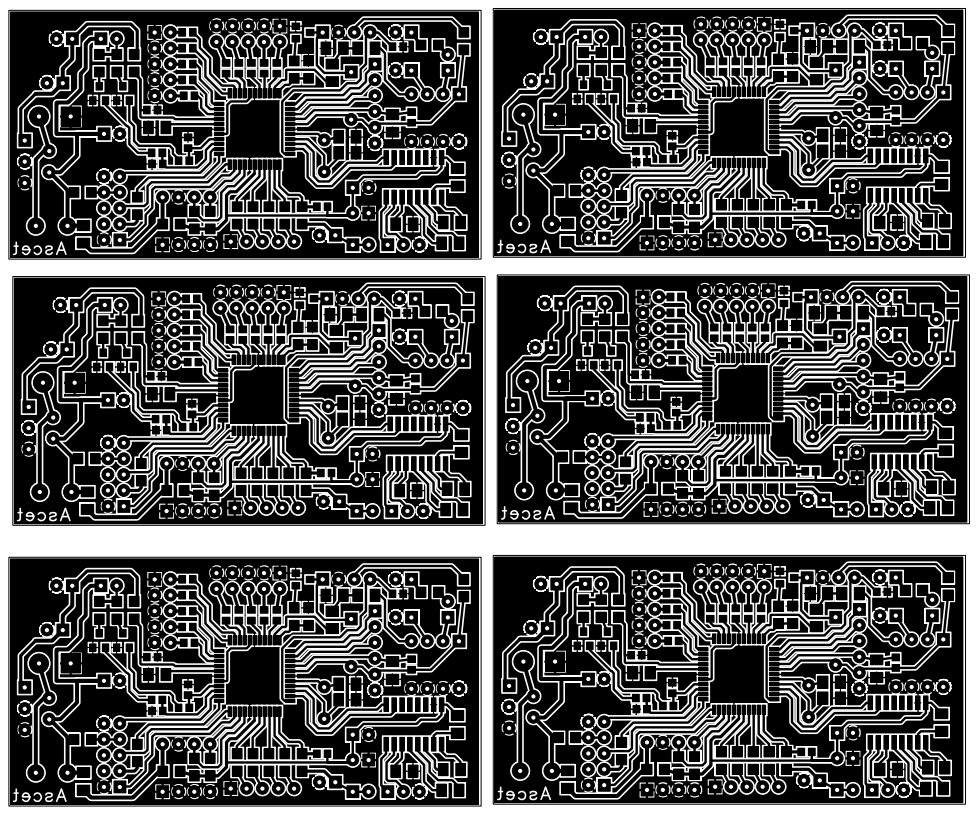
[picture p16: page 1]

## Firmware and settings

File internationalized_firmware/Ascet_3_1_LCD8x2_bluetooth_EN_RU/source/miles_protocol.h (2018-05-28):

#define IR_START_BIT_DURATION 2400	// Длительность Старт-Бита (в микросекундах)
#define IR_ONE_BIT_DURATION 1200	// Длительность Бита, соотретствующего единичке (в микросекундах)
#define IR_ZERO_BIT_DURATION 600	// Длительность Бита, соотретствующего нулю (в микросекундах)
#define IR_SPACE_DURATION 600		// Длительность Бита, соотретствующего интервалу между битами (в микросекундах)
//#define IR_F0 miles_protocol.carrier_frequency /*56000*/					// Несущая частота ИК-приемника (f0)
#define IR_F0 36000
#define ERROR_TOLERANCE miles_protocol.err_tolerance //14//22 //Допустимая погрешность длительности принимаемых бит (в "тиках" таймера)


#define ERROR_TOLERANCE_FOR_36KHZ 12//14
#define ERROR_TOLERANCE_FOR_56KHZ 19//22


#define DEFAULT_IR_F0 36000					// Несущая частота ИК-приемника (f0)
#define DEFAULT_ERROR_TOLERANCE 12//14 //Допустимая погрешность длительности принимаемых бит (в "тиках" таймера)


#define IR_ZERO miles_protocol.ir_zero//(IR_ZERO_BIT_DURATION*2*IR_F0)/1000000 //Длительность импулся, соответствующего биту = 0
													  //выраженная в "тиках" таймера 


#define RX_IR_ZERO (IR_ZERO_BIT_DURATION*8)/1000 //Длительность импулся, соответствующего биту = 0
													  //выраженная в "тиках" таймера 



#define IR_ONE miles_protocol.ir_one//(IR_ONE_BIT_DURATION*2*IR_F0)/1000000 //Длительность импулся, соответствующего биту = 1
													  //выраженная в "тиках" таймера 

#define RX_IR_ONE (IR_ONE_BIT_DURATION*8)/1000 //Длительность импулся, соответствующего биту = 1
													  //выраженная в "тиках" таймера 



#define IR_START miles_protocol.ir_start//(IR_START_BIT_DURATION*2*IR_F0)/1000000 //Длительность заголовка 
														//выраженная в "тиках" таймера 


#define RX_IR_START (IR_START_BIT_DURATION*8)/1000 //Длительность заголовка 
														//выраженная в "тиках" таймера 


#define IR_SPACE  miles_protocol.ir_space//(IR_SPACE_DURATION*2*IR_F0)/1000000 //Длительность интервала между передоваемыми битами
														//выраженная в "тиках" таймера 


#define RX_IR_SPACE  (IR_SPACE_DURATION*8)/1000 //Длительность интервала между передоваемыми битами
														//выраженная в "тиках" таймера 


#define  SAFE_DURATION eeprom_read_byte(&eeprom_safe_duration)//5      //время (в десятых секунды) неуязвимости после ранения




//#define ERROR_TOLERANCE 14

//#define ERROR_TOLERANCE 2


//---------------------------------------------------------------------//

enum Team_Color {	//Определим перечисляемый тип для работы с цветом команды
	Red, 	//00 = Red
	Blue, 	//01 = Blue		
	Yellow, //10 = Yellow
	Green}; //11 = Green

typedef enum Team_Color tteam_color;			

//---------------------------------------------------------------------//





//Определим перечисляемый тип
//для работы с "уроном"
enum GunDamage {	
	
	Damage_1,  //0000 = 1
	Damage_2,  //0001 = 2
	Damage_4,  //0010 = 4
	Damage_5,  //0011 = 5
	Damage_7,  //0100 = 7
	Damage_10, //0101 = 10
	Damage_15, //0110 = 15
	Damage_17, //0111 = 17
	Damage_20, //1000 = 20
	Damage_25, //1001 = 25
	Damage_30, //1010 = 30
	Damage_35, //1011 = 35
	Damage_40, //1100 = 40
	Damage_50, //1101 = 50
	Damage_75, //1110 = 75
	Damage_100 //1111 = 100
	};
	
	    								
typedef enum GunDamage tgun_damage; 	




//---------------------------------------------------------------------//


/*
union player_id_union {
tplayer_id bits;
uint8_t data [8];
};
*/

#define Add_Health 0x80 //сообщение добавить жизни
#define Add_Rounds 0x81 //сообщение добавить патронов
#define Change_color 0xA9//сообщение сменить цвет команды 
#define Command 0x83 //сообщение-команда
#define Valid_value 0xE8 //корректное значение контрольного байта сообщения
#define Set_life 0xA3 //установить хх жизней
#define Set_damage 0xA8 //установить хх урон

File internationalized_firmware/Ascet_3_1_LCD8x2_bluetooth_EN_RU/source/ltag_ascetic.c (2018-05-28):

#include "ltag_ascetic.h"
#include "lcd_driver.h"
#include "tm_driver.h"
#include "i2c_eeprom.h"
#include "commands.h"




int main (void) {
configuring_ports();
get_ir_protocol();
init_timer2();
init_int0();
init_tm();	//инициализируем считыватель тачмемори
init_timer1();
init_timer0();

init_var();                		//Задаём значения переменным

init_lcd(); 
lcd_clrscr();
init_joystick();
init_adc();

USART_Init();
EnableRxInt();
EnableTxInt();


eeInit();


_delay_ms(15); 
lcd_puts("LTAscet");
lcd_gotoxy(0, 1);
lcd_puts("Russia");
lcd_generate_additional_symbols();

sei(); 

life_leds_status[0] = ON;
timer2 = 0;
while (timer2 < 1000);

life_leds_status[1] = ON;
timer2 = 0;
while (timer2 < 1000);

//LIFE_LED3_ON;
life_leds_status[2] = ON;
timer2 = 0;
while (timer2 < 1000);

//LIFE_LED4_ON;
life_leds_status[3] = ON;
timer2 = 0;
while (timer2 < 1000);

//FIRE_LED_ON;
fire_led_status = ON;
timer2 = 0;
while (timer2 < 1000);

BULLETS_OUT_LED_ON;
timer2 = 0;
while (timer2 < 1000);


BT_STATE_LED_ON;
timer2 = 0;
while (timer2 < 1000);

WOUND_LED_ON;
timer2 = 0;
while (timer2 < 1000);

FIRE_LED_ON;
timer2 = 0;
while (timer2 < 1000);



lcd_bl_on();
timer2 = 0;
while (timer2 < 1000);


lcd_bl_off();
timer2 = 0;
while (timer2 < 1000);

//LIFE_LED1_OFF;
life_leds_status[0] = OFF;
timer2 = 0;
while (timer2 < 1000);

//LIFE_LED2_OFF;
life_leds_status[1] = OFF;
timer2 = 0;
while (timer2 < 1000);

//LIFE_LED3_OFF;
life_leds_status[2] = OFF;
timer2 = 0;
while (timer2 < 1000);

//LIFE_LED4_OFF;
life_leds_status[3] = OFF;
timer2 = 0;
while (timer2 < 1000);

FIRE_LED_OFF;
timer2 = 0;
while (timer2 < 1000);

BT_STATE_LED_OFF;
timer2 = 0;
while (timer2 < 1000);

BULLETS_OUT_LED_OFF;
timer2 = 0;
while (timer2 < 1000);

WOUND_LED_OFF;
timer2 = 0;
while (timer2 < 1000);

timer2 = 0;
while (timer2 < 1000);


display_life(life);
beep(1000, 3, 128);

USART_SendStr("Ascet 3.1\n\r");//приветствие


invite();
life_in_percent =eeprom_read_byte(&life_after_start);
//cut_off_sound = (eeprom_read_word(&sound_1_size)/100)*(100-CUT_OFF_SOUNT);
set_cyclic_deley_counter();

joystick_event=no_pressing;
display_status();
USART_FlushRxBuf();
bt_header_received=false;
timer2 = 0;

while (timer2 < 1000);


while(1){

if (simples_in_queue==0) display_voltage_update();


if (chit_detected)
	{
		lcd_clrscr();
#if LANGUAGE == RU
		lcd_puts(" Ошибка ");
#elif LANGUAGE == EN
		lcd_puts(" Sensor ");
#endif		
		lcd_gotoxy(0, 1);
#if LANGUAGE == RU
		lcd_puts("датчика!");
#elif LANGUAGE == EN		
		lcd_puts(" error! ");
#endif

		while (chit_detected)
		{
			beep(1000, 3, 128);
			beep(500, 3, 128); //Воспроизводим звук (частота, длительность, громкость)
		};
		
		USART_FlushRxBuf();
		keyboard_event=no_key_pressing;
		reload_key_event=no_key_pressing;
		joystick_event = no_pressing;
		display_status();
	}


switch(reload_key_event)
	{
	 	case no_key_pressing: break;
		case key_pressing:
		{
			if (reload_state==nothing_to_do)
			{
				
				if ((clips > 0)&&(curr_sound.simples_in_queue==0))//если обоймы не кончилсь и не воспроизводиться звук выстрела
				{	
					reload_countdown =  eeprom_read_byte(&eeprom_reload_duration)*8;
					reload_state=waiting_countdown;
					playback_sound(clip_out_sound);
					reload_key_event=no_key_pressing; 
					//playclipinsound();
				}
			}
			
			
			
		} 
        break;
  
		default:reload_key_event=no_key_pressing;	
		}


		{
		switch(rx_event)//выясним, какое именно событие произошло
					{
						case RX_COMPLETE: 	//получен пакет
						{						
							rx_event = NOT_EVENT;	
							if(!get_buffer_bit(0)) //если этот бит равен 0, то это пакет с данными (выстрел)
							{
								rx_packet = get_packet_value();
								hit_processing(rx_packet);
								rx_event = NOT_EVENT;
							}
							break;
						}
						
						case RX_MESSAGE_COMPLITE://принято сообщение
						{
							rx_event = NOT_EVENT;							
							if(get_buffer_bit(0)) //если этот бит равен 1, то это пакет с командой
                        	{
                           		ir_message = get_ir_message_from_buffer();//выдергиваем значения команды из буфера ИК приемника
                        
                           	 if (ir_message.control_byte ==Valid_value )//сообщение принято корректно (контрольный байт принят без ошибок)
							 {
								switch(ir_message.ID)//если имя команды
                           		{
                              		case Add_Health: //добавить "жизни"
                              		{
										//код для добавления жизни
                                 		break;
                              		}
                              		case Add_Rounds://добавить "патронов"
                              		{
                                 
								 		//код для добавления патронов
                                 		break;
                              		}

                              		case Change_color:
									{
										//код для смены цвета
										if((ir_message.param>=0)&&(ir_message.param<=3))
										{
											eeprom_write_byte(&eeprom_team_id,ir_message.param );	
											set_team_color(team_id());	//Устанавливаем идентификатор (цвет) команды
											for (uint8_t i=0; i <ir_message.param; i++ )
											{
													beep(1000, 2, 128);
													timer2 = 0;
													while (timer2 < 1000);
											};
											beep(1000, 2, 128);
										}
										else
										{
											//ошибка смены цвета
											
											beep(1000, 3, 128);
											beep(500, 3, 128); //Воспроизводим звук (частота, длительность, громкость)											
											beep(1000, 3, 128);
											beep(500, 3, 128); //Воспроизводим звук (частота, длительность, громкость)
										}
										
																				
										break;
									}
									case Set_life:// установить хх жизней
									{
										life_in_percent = ir_message.param;
										life = (life_in_percent*10)/125;
										if ((life==0)&&(life_in_percent>0)) life=1;
										status_need_update = true;
										eeprom_write_byte(&life_after_start,ir_message.param);
										beep(1000, 2, 128);
										break;
									}
									case Set_damage://установить хх урон
									{
										eeprom_write_byte(&eeprom_damage,ir_message.param);
										set_gun_damage(gun_damage());
										beep(1000, 2, 128);
										break;
									}
																				  
									  
									case Command://какая то дополнительноя команда
                              		{
                                    	
										switch(ir_message.param)//выясним, какая это командв
										{

											
											
											case 0x05://начать новую игру немедленно
											{
												if((reload_state!=nothing_to_do)||(simples_in_queue!=0)||(curr_sound.simples_in_queue!=0)||(eeprom_is_open)) break;
												new_game();
												
												break;
											}
											case 0x00://"выключить" игрока 
											{
												
												game_over();
												break;
												
											}
											default: break;
										
										}
										
									
										break;
                              		}
                           		}
                        	 }

                        	}
							else//контрольный байт сообщения не корректный - ошибка приема
							{
							}
							
							
							
							
							rx_event = NOT_EVENT;
							break;

						}
						
						
						case RX_ERROR:		//ошибка приема
						{
							if((reload_state!=nothing_to_do)||(simples_in_queue!=0))
							{
								rx_event = NOT_EVENT;
								break;
							}


                            if((!ir_error_ignore)&&(!eeprom_is_open))//если не надо игнорировать ошибку и звук не воспроизводиться уже
                            {
						//	cli();
						//	BULLETS_OUT_LED_ON;
							
							playback_sound(flying_bullet_sound);
							/*
							timer2=0;
							while(timer2 < 4000);
							*/
							//BULLETS_OUT_LED_OFF;
                            }
                            rx_event = NOT_EVENT;
						//	sei();
							break;
						}
						
						case NOT_EVENT:		//ошибка приема
						{
						//	cli();
						//	rx_event = NOT_EVENT;	
						//	sei();
							break;
						}



					}



	}

if (rxCount>0)//если буфер BT приемника не пустой
	{
		test_bt_data();
	}
	

switch(keyboard_event)
	{
	 	case no_key_pressing: break;
		case key_pressing:
		{
			if(((curr_sound.role==hit_sound)&&(curr_sound.simples_in_queue>0))||(rx_event==RX_COMPLETE))//если звук ранения ещё играет
			{
				keyboard_event=no_key_pressing; //ничего не делаем
				break;
			}
			if(reload_state==nothing_to_do)
			{
				if (bullets > 0)
				{
					bullets--;//уменьшаем на 1 количество патронов		
					//last_simple = 0;//воспроизводим звук выстрела
				/*
					if (simples_in_queue>1) //если звук выстрла воспроизводится
					{
						simples_in_queue=1;//закроем eeprom
						while (eeprom_is_open);//дождемся, пока eerom закроется
					}
				 
					simples_in_queue = eeprom_read_word(&sound_1_size);
				*/
					playback_sound(shot_sound);
					send_ir_package();		//Производим "выстрел"
			//	display_bullets_update();
				
	 			}
			
			
				else // патронов в магазине нет
			
				{
					if (simples_in_queue==0) //если звук выстрла не воспроизводится
					{
							playback_sound(misfire_sound);
						//play_sound_5();//воспроизводим звук осечки
					}
				}
			
			}
			
			keyboard_event=no_key_pressing; 
		} 
        break;
  

		default:keyboard_event=no_key_pressing;	
	}

switch (reload_state)
	{
		case nothing_to_do:
		{
			
		}
		break;
		case waiting_countdown:
		{
			
		}
		break;
		case reload_now:
		{
			clips--;//уменьшаем на 1 количество патронов
			bullets = eeprom_read_byte(&eeprom_bullets_in_clip);
			display_clips_update();
			display_bullets_update();
			BULLETS_OUT_LED_OFF;
			
			if(!((curr_sound.role==hit_sound)&&(curr_sound.simples_in_queue>0))) playback_sound(clip_in_sound);
		//	playclipoutsound();
			reload_state = nothing_to_do;
			reload_key_event=no_key_pressing;
		}
		break;
	}

if (status_need_update) 
	{
		if (!((curr_sound.role==hit_sound)&&(curr_sound.simples_in_queue>0)))//если не играет звук ранения
		{
			display_status();
			display_life(life);//отобразим уровень жизни на диодах
			status_need_update = false;
		}
		
	}

switch(joystick_event)
	{
		case key_up_pressing: 
			{
				switch(display_batt_mode)
				{
					case icon: display_batt_mode=digit;
					break;
					case digit: display_batt_mode=icon;
				}
			
			
			
			joystick_event = no_pressing;
			}
	
		break;
		case key_right_pressing: 
			{
				joystick_event = no_pressing;
			}
		break;
		case key_down_pressing: 
			{
				joystick_event = no_pressing;
			}
		break;
		case key_left_pressing: 
			{
				joystick_event = no_pressing;
			}
		break;
		case key_central_pressing: 
			{
			joystick_event = no_pressing;
			}
		break;
		default: joystick_event = no_pressing;
	
	
		}
	
	if (display_bullets_update_now>0) 
		{
			display_bullets_update();
			display_bullets_update_now--;
		}

	};
return 0;

}




void configuring_ports(){
//IR_LED_DDR |= IR_LED_PIN; //ножку, на которой подключен ИК диот переводим в режим "выход"
FIRE_LED_DDR |= FIRE_LED_PIN; //ножку, на которой подключен ИК диот переводим в режим "выход"
BT_STATE_LED_DDR |= BT_STATE_LED_PIN;//ножку, к которой подключен сетодиод статуса блютус соединения - как выход


IR_LED_HIGH_POWER_DDR|=IR_LED_HIGH_POWER_PIN;//ножку, на которой подключен ИК диот переводим в режим "выход"
IR_LED_HIGH_POWER_OFF;
IR_LED_LOW_POWER_DDR|=IR_LED_LOW_POWER_PIN;//ножку, на которой подключен ИК диот переводим в режим "выход"
IR_LED_LOW_POWER_OFF;

LIFE_LED1_DDR |= LIFE_LED1_PIN;
LIFE_LED2_DDR |= LIFE_LED2_PIN;
LIFE_LED3_DDR |= LIFE_LED3_PIN;
LIFE_LED4_DDR |= LIFE_LED4_PIN;


SOUND_DDR |= SOUND_PIN; //настраиваем выход ШИМ (АЦП)
SOUND_CONTROL_DDR|= SOUND_CONTROL_PIN;//настраиваем вывод, контролирующий усилитель, как "выход" 
SOUND_ON;//включаем усилитель

BULLETS_OUT_LED_DDR|=BULLETS_OUT_LED_PIN;

DDRB |= (1 << 2);// отключение усилителя
PORTB &=~(1 << 2);
//PORTD &= ~(1 << 7);//выключаем светодиод на повязке
WOUND_LED_DDR |= WOUND_LED_PIN;
TSOP_DDR &=~TSOP_PIN; //вывод, к которому подключен ИК-датчик настраиваем как "вход"
RELOAD_KEY_DDR &=~RELOAD_KEY_PIN; //вывод, на котором сидит кнопка "перезарядка" как "вход"
RELOAD_KEY_PORT |= RELOAD_KEY_PIN;//включаем подтягивающий резистор

FIRE_KEY_DDR&=~FIRE_KEY_PIN;
FIRE_KEY_PORT|=FIRE_KEY_PIN;

FIRE_MODE_KEY_DDR&=~FIRE_MODE_KEY_PIN;
FIRE_MODE_KEY_PORT|=FIRE_MODE_KEY_PIN;


BT_STATE_PORT&=~BT_STATE_PIN;

ADC_DDR&=~ADC_PIN;
ADC_PORT&=~ADC_PIN;
}


/**************************************************************************************
* Функция выполняет настройку таймера timer2
* Режим работы таймер - СТС (сброс при совпадении)
* тактирование - без делителя, с частотой кварца
* регист сравнения будет иметь такое значение, чтобы прерывания
* генерировались с удвоенной частотой несущей ИК-приемника 
***************************************************************************************/


void init_timer2(void){
OCR2 = (F_CPU/1000)/(miles_protocol.carrier_frequency/1000)/2-1;       //Прерывания будут генерироваться с частотой, вдвое большей, чем частота несущей 
TCCR2 = _BV(CS20)|_BV(WGM21); // Режим работы таймер - СТС (сброс при совпадении)
                              // Тактирование с частотой резонатора (7 372 800 Гц)
//TIMSK |= _BV(OCIE2);          // Разрешаем прерывания по захвату/сравнению
TIMSK &=~_BV(OCIE2);  
}



void reinit_timer2(void){
OCR2 = (F_CPU/1000)/(miles_protocol.carrier_frequency/1000)/2-1;   

}
/**************************************************************************************
* Функция выполняет настройку внешних прерываний вывода INT0
***************************************************************************************/
void init_int0(void){
DDRD &=~(1<<2); 				//Настраиваем вывод INT0 как вход
MCUCR |=_BV(ISC01);				//Прерывания будут генерироваться 
MCUCR &=~_BV(ISC00);			//по спаду импульса
GICR |=_BV(INT0); 				//Разрешаем внешние прерывания на INT0

}



void set_buffer_bit(uint8_t index, bool value){	//Задаем значение биту в буфере ИК-приемника
uint8_t byte_index;
uint8_t bit_index;
byte_index = index/8; //Определяем, в каком байте нахадится нужный бит
bit_index = index - (byte_index*8);//Определяем номер бита в байте
if(value) 
		{
			rx_buffer[byte_index] |= (1<<(7-bit_index));
		}
else	{
			rx_buffer[byte_index] &= ~(1<<(7-bit_index));
		}
}


void set_bt_buffer_bit(uint8_t index, bool value){	//Задаем значение биту в буфере ИК-приемника
uint8_t byte_index;
uint8_t bit_index;
byte_index = index/8; //Определяем, в каком байте нахадится нужный бит
bit_index = index - (byte_index*8);//Определяем номер бита в байте
if(value) 
		{
			bt_rx_buffer[byte_index] |= (1<<(7-bit_index));
		}
else	{
			bt_rx_buffer[byte_index] &= ~(1<<(7-bit_index));
		}
}



/**************************************************************************************
* Функця производит "выстрел"
* устанавлвает курсор на позицию начала блока данных data_packet.data[0]
* и разрешает передачу данных
* функция возвращает управление  только после отправки всех данных 
***************************************************************************************/


void send_ir_package(void){ //Отправляем пакет ("стреляем")
ir_error_ignore = DEFAULT_IR_ERROR_IGNORE;
set_cyclic_deley_counter();
ir_tx_cursor_home();//Курсор - на начало буфера
ir_tx_buffer_cursor.bits_for_tx=14;//"выстрел" состоит из 14 бит
ir_transmitter_on = true;	//Разрешаем передачу
TIMSK |= _BV(OCIE2);          // Разрешаем прерывания по захвату/сравнению
FIRE_LED_ON;

}

/**************************************************************************************
* Установка идентификатора игрока
* в качестве аргумента функции указывается идентификационный номер игрока (от 1 до 127)
* в результате выполнения функции в глобальной переменной data_packet.player_id
* будут соответствующим образом инициированы  data_packet.player_id.(bit_0 ... bit_7) 
***************************************************************************************/
void set_player_id(uint8_t ID){
tx_buffer[0]= ID;
tx_buffer[0] &=~(1<<7);//седьмой бит в выстреле всегда равен "0"

}



/**************************************************************************************
* Установка идентификатора (цвета) команды
* в качестве аргумента функции указывается идентификационный номер (цвет) команды (от 0 до 3)
* в результате выполнения функции в глобальной переменной data_packet.team_id
* будут соответствующим образом инициированы  data_packet.team_id.(bit_0 и bit_1) 
***************************************************************************************/



void set_team_color(tteam_color  color){
tx_buffer[1] &=~((1<<7)|(1<<6));//обнуляем два старших бита 
tx_buffer[1] |=(color <<6);//устанавливаем 6 и 7 биты в соответствии с цветом команды
}




/**************************************************************************************
* Установка установка мощьности нашего оружия (наносимый урон)
* в качестве аргумента функции указывается наносимый урон
* в результате выполнения функции в глобальной переменной data_packet.damage
* будут соответствующим образом инициированы  data_packet.damage.(bit_0 и bit_3) 
***************************************************************************************/


void set_gun_damage(tgun_damage damage){
tx_buffer[1] &=~((1<<5)|(1<<4)|(1<<3)|(1<<2));//обнуляем биты урона 
tx_buffer[1] |=(damage << 2);
}




void init_var(void){            //Задаём значения переменным
check_eeprom();
last_simple = 0xFFFF; //иначе будет звук выстрела при сбросе
snd_adress.curr_adress = (uint8_t*)0xFFFF; //иначе бубдет попытка воспроизвести звук
ir_transmitter_on=false; 	//Запретим пока передачу данных (поскольку данные ещё не сформированны)
set_player_id(eeprom_read_byte(&eeprom_player_id));	//Устанавливаем идентификатор игрока
set_team_color(team_id());	//Устанавливаем идентификатор (цвет) команды
set_gun_damage(gun_damage());		//Устанавливаем мощьность оружия (урон)

clips=eeprom_read_byte(&eeprom_clips);//Устанавливаем количество обойм
bullets=0; //eeprom_read_byte(&eeprom_bullets_in_clip);//Устанавливаем количество патронов
cursor_position = 0; //Курсор - на начало блока данных
start_bit_received = false;//Старт бит ещё не принят
bit_in_rx_buff = 0;//Буфер приемника пуст
bit_in_bt_rx_buff = 0;//Буфер приемника блютус пуст
rx_event = NOT_EVENT;//Сбрасываем события приемника
bt_rx_event = NOT_EVENT;//Сбрасываем события BT приемника
life = 8;//здоровье -100% выводим на диоды
life_in_percent =eeprom_read_byte(&life_after_start);
key_pressing_duration.key_1    =0;//обнуляем счетчики 
						  //длительности
						  //непрерывного нажатия кнопок
key_pressing_duration.key_1_inc=1;//разрешаем отсчет длительности
key_pressing_duration.key_2    =0;//обнуляем счетчики 
						  //длительности
						  //непрерывного нажатия кнопок
key_pressing_duration.key_2_inc=1;//разрешаем отсчет длительности
chit_detected_counter=0;
chit_detected = false;
display_bullets_update_now = 0;
display_batt_mode = icon;
curr_ir_pin = eeprom_read_byte(&eeprom_curr_ir_pin);//Устанавливаем мощность ИК излучения
cr_received = false; //символ "\r" ещё не получен
bt_header_received = false; //символ "h" ещё не получен
simples_in_queue =0;
curr_sound.simples_in_queue=0;
eeprom_is_open = false;
receiver_on = false;
ir_error_ignore = 0; //не игнорируем ошибочные пакеты
reload_state = nothing_to_do;
reload_countdown=0;
status_need_update = true;
safe_counter = 0;//обратный счетчик времени неуязвимости после ранения
cyclic_deley_counter = (60000/eeprom_read_word(&eeprom_cyclic_rate))*8;//задержка между выстрелами при автоматической стрельбе в тиках таймера
}




bool get_buffer_bit(uint8_t index){		//Считываем значение бита в буфере ИК-приемника
uint8_t byte_index;
uint8_t bit_index;
byte_index = index/8; //Определяем, в каком байте нахадится нужный бит
bit_index = index - (byte_index*8);//Определяем номер бита в байте
if(rx_buffer[byte_index]&(1<<(7-bit_index))) return true;
else return false;


}

bool get_bt_buffer_bit(uint8_t index){		//Считываем значение бита в буфере ИК-приемника
uint8_t byte_index;
uint8_t bit_index;
byte_index = index/8; //Определяем, в каком байте нахадится нужный бит
bit_index = index - (byte_index*8);//Определяем номер бита в байте
if(bt_rx_buffer[byte_index]&(1<<(7-bit_index))) return true;
else return false;


}
inline trx_packet get_packet_value(){ //Считываем данные из полученного пакета
trx_packet result;
uint8_t byte_tmp;

result.player_id = rx_buffer[0];
byte_tmp = rx_buffer[1];
byte_tmp = byte_tmp << 2; //избавляемся от бит цвета команды
byte_tmp = byte_tmp >> 4;
result.damage = pgm_read_byte(&(damage_value[byte_tmp]));
result.team_id = rx_buffer[1]>>6;

return result;
}



inline trx_packet get_bt_packet_value(){ //Считываем данные из полученного пакета
trx_packet result;
uint8_t byte_tmp;

result.player_id = bt_rx_buffer[0];
byte_tmp = bt_rx_buffer[1];
byte_tmp = byte_tmp << 2; //избавляемся от бит цвета команды
byte_tmp = byte_tmp >> 4;
result.damage = pgm_read_byte(&(damage_value[byte_tmp]));
result.team_id = bt_rx_buffer[1]>>6;

return result;
}




tteam_color team_id()//Опреднляем цвет нашей команды 
{
tteam_color result;
result = eeprom_read_byte(&eeprom_team_id);
return result;
}



void write_team_id_to_eeprom(tteam_color color){
eeprom_write_byte(&eeprom_team_id, color);

}


/**************************************************************************************
* Функция выполняет настройку таймера timer0
* Режим работы таймер - СТС (сброс при совпадении)
* тактирование - с предделителем на 1024
* регист сравнения будет иметь такое значение, чтобы прерывания
* генерировались 100 прерываний в секунду 
***************************************************************************************/

void init_timer0(void){
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

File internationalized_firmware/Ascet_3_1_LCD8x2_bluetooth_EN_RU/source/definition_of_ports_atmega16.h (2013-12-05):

#define ADC_PORT PORTA
#define ADC_DDR DDRA
#define ADC_PIN (1<<7)
#define ADC_CHANNEL 7


#define IR_LED_PORT PORTC 
#define IR_LED_DDR DDRC 

#define IR_LED_HIGH_POWER_PORT PORTC 
#define IR_LED_HIGH_POWER_DDR DDRC 

#define IR_LED_LOW_POWER_PORT PORTC 
#define IR_LED_LOW_POWER_DDR DDRC 


#define LIFE_LED1_PORT PORTC
#define LIFE_LED1_DDR DDRC
#define LIFE_LED2_PORT PORTC
#define LIFE_LED2_DDR DDRC
#define LIFE_LED3_PORT PORTC
#define LIFE_LED3_DDR DDRC
#define LIFE_LED4_PORT PORTD
#define LIFE_LED4_DDR DDRD

#define FIRE_LED_PORT PORTC
#define FIRE_LED_DDR DDRC
#define BT_STATE_LED_PORT PORTA
#define BT_STATE_LED_DDR DDRA

#define BULLETS_OUT_LED_PORT PORTA
#define BULLETS_OUT_LED_DDR DDRA
#define SOUND_PORT PORTB
#define SOUND_DDR DDRB
#define TSOP_PORT PORTD
#define TSOP_DDR DDRD
#define TSOP_IN PIND
#define WOUND_LED_PORT PORTD
#define WOUND_LED_DDR DDRD
#define FIRE_KEY_PORT PORTB
#define FIRE_KEY_DDR DDRB
#define FIRE_KEY_IN PINB

#define RELOAD_KEY_PORT PORTB //Порт, к которому подключен переключатель "DAMAGE" (урон)
#define RELOAD_KEY_DDR DDRB 
#define RELOAD_KEY_IN PINB



#define FIRE_MODE_KEY_PORT PORTB
#define FIRE_MODE_KEY_DDR DDRB
#define FIRE_MODE_KEY_IN PINB

#define SOUND_CONTROL_PORT PORTB
#define SOUND_CONTROL_DDR DDRB

#define  BT_STATE_PORT PORTD
#define  BT_STATE_DDR DDRD
#define  BT_STATE_IN PIND
#define  BT_STATE_PIN (1<<5)
#define  BT_STATE_LED_PIN (1<<1)

//#define IR_LED_PIN (1<<5)

#define IR_LED_HIGH_POWER_PIN (1<<6)

#define IR_LED_LOW_POWER_PIN (1<<7)


#define FIRE_LED_PIN (1<<5)
#define BULLETS_OUT_LED_PIN (1<<0)
#define LIFE_LED1_PIN (1<<3)
#define LIFE_LED2_PIN (1<<4)
#define LIFE_LED3_PIN (1<<2)
#define LIFE_LED4_PIN (1<<7)
#define WOUND_LED_PIN (1<<4)


#define SOUND_PIN (1<<3)
#define SOUND_CONTROL_PIN (1<<4)

#define TSOP_PIN (1<<2)

#define FIRE_KEY_PIN (1<<2)
#define RELOAD_KEY_PIN (1<<0)
#define FIRE_MODE_KEY_PIN (1<<1)

/*
#define SW_DAMAGE_PORT PORTB //Порт, к которому подключен переключатель "DAMAGE" (урон)
#define SW_DAMAGE_DDR DDRB 
#define SW_DAMAGE_IN PINB
#define SW_DAMAGE_MASK ((1<<0)|(1<<1))
#define SW_DAMAGE_KEY1_PIN (1<<0)
#define SW_DAMAGE_KEY2_PIN (1<<1)


#define SW_TEAM_PORT PORTA //Порт, к которому подключен переключатель "TEAM_ID" (цвет команды)
#define SW_TEAM_DDR DDRA
#define SW_TEAM_IN PINA
#define SW_TEAM_MASK ((1<<0)|(1<<1))
#define SW_TEAM_KEY1_PIN (1<<0)
#define SW_TEAM_KEY2_PIN (1<<1)



#define SW_BULLETS_LIMIT_PORT PORTD //Порт, к которому подключен переключатель "BULLETS_LIMIT" (лимит патронов)
#define SW_BULLETS_LIMIT_DDR DDRD
#define SW_BULLETS_LIMIT_IN PIND
#define SW_BULLETS_LIMIT_MASK ((1<<5)|(1<<6))
#define SW_BULLETS_LIMIT_KEY1_PIN (1<<5)
#define SW_BULLETS_LIMIT_KEY2_PIN (1<<6)
*/

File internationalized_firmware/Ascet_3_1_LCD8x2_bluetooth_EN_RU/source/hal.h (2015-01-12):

#ifndef F_CPU						//Этот параметр нужно задавать в свойствах проекта, если там не задан, задаем здесь
#define F_CPU 16000000  			// Тактовая частота в Гц
#endif



#define LIFE_LED1_ON LIFE_LED1_PORT|=LIFE_LED1_PIN
#define LIFE_LED1_OFF LIFE_LED1_PORT&=~LIFE_LED1_PIN
#define LIFE_LED2_ON LIFE_LED2_PORT|=LIFE_LED2_PIN
#define LIFE_LED2_OFF LIFE_LED2_PORT&=~LIFE_LED2_PIN
#define LIFE_LED3_ON LIFE_LED3_PORT|=LIFE_LED3_PIN
#define LIFE_LED3_OFF LIFE_LED3_PORT&=~LIFE_LED3_PIN
#define LIFE_LED4_ON LIFE_LED4_PORT|=LIFE_LED4_PIN
#define LIFE_LED4_OFF LIFE_LED4_PORT&=~LIFE_LED4_PIN
#define FIRE_LED_ON FIRE_LED_PORT|=FIRE_LED_PIN
#define FIRE_LED_OFF FIRE_LED_PORT&=~FIRE_LED_PIN
#define BT_STATE_LED_ON BT_STATE_LED_PORT|=BT_STATE_LED_PIN
#define BT_STATE_LED_OFF BT_STATE_LED_PORT&=~BT_STATE_LED_PIN
#define BULLETS_OUT_LED_ON BULLETS_OUT_LED_PORT|=BULLETS_OUT_LED_PIN
#define BULLETS_OUT_LED_OFF BULLETS_OUT_LED_PORT&=~BULLETS_OUT_LED_PIN
#define	WOUND_LED_ON WOUND_LED_PORT|=WOUND_LED_PIN
#define	WOUND_LED_OFF WOUND_LED_PORT&=~WOUND_LED_PIN
#define	WOUND_LED_INVERT WOUND_LED_PORT^=WOUND_LED_PIN
#define SOUND_ON SOUND_CONTROL_PORT|=SOUND_CONTROL_PIN
#define SOUND_OFF SOUND_CONTROL_PORT&=~SOUND_CONTROL_PIN

//#define IR_LED_INVERT IR_LED_PORT^=IR_LED_PIN
#define IR_LED_INVERT IR_LED_PORT^=curr_ir_pin



#define IR_LED_HIGH_POWER_OFF IR_LED_PORT&=~IR_LED_HIGH_POWER_PIN

#define IR_LED_LOW_POWER_OFF IR_LED_PORT&=~IR_LED_LOW_POWER_PIN

#define IR_LED_OFF IR_LED_HIGH_POWER_OFF;IR_LED_LOW_POWER_OFF


#define LIFE_LED1_INVERT LIFE_LED1_PORT^=LIFE_LED1_PIN
#define FIRE_LED_INVERT FIRE_LED_PORT^=FIRE_LED_PIN



#define OFF 0b00000000
#define FQR_1HZ 0b11110000
#define FQR_2HZ 0b11001100
#define FQR_4HZ 0b10101010
#define ON 0b11111111

#define SHORT_DURATION 4 	//минимальная длительность (в "тиках") непрерывного нажатия курка, 
							//необходимая для фиксации события "курок нажат"


#define CUT_OFF_SOUNT 10 //Длительность звука в режиме "очередь" в процентах от длительности звука в режиме "одиночный"


#define CYCLIC_RATE eeprom_read_word(&eeprom_cyclic_rate)//250

#define DEFAULT_BATT_FULL_VOLTAGE 6800 //напряжение полностью заряженной батареи в милливольтах

#define DEFAULT_BATT_LOW_VOLTAGE 5500 //напряжение полностью разряженной батареи в милливольтах

#define DEFAULT_IR_ERROR_IGNORE 80 //игнорируем ошибки приема в течение 1 с после выстрела

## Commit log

2011-12-19 error in coding pages
    [definition_of_ports_atmega16.h, hal.h, ltag_ascetic.c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]
2012-01-12 Добавлена функция beep() для воспроизведения звука
2012-04-02 Добавлена версия прошивка для Атмега32
    [LTAscetic.dsn]
2012-08-27 Add new version LTAscetic
    [LCD_SMD_SHIELD.dsn, LTAsceticRelease2.dsn]
2012-12-29 Add new release LTAscetic - 3
    [IR_DETECTOR_TSOP4836.dsn, LCD_SMD_SHIELD.dsn, LTAscetic_3.dsn]
2013-04-22 Add new release LTAscetic - 3.1
    [LTAscet_3_1_RS232_modul.dsn, LTAscet_3_1_matheboard.dsn, LTAscet_StepUp_DCDC_modul.dsn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]
2013-05-08 Changes are made to a bluetooth the module
    [bluetooth_modul_BoardOutline.gbr, bluetooth_modul_BottomMask.gbr, bluetooth_modul_TopMask.gbr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]
2013-10-01 Fix error in LCD shield PCB
    [lcd_modul_top.gbr]
2013-12-05 Added wireless firmware
2014-10-02 Update ltag_ascetic.c
    Fix error in "switch" operator - add "break;"
    [ltag_ascetic.c]
2014-10-03 corrected Bluetooth bandana firmware
    [hal.h, ltag_ascetic.c]
2014-11-13 in reload time main loop work, fix bug in parsing_bt_data() fumction
    [i2c_eeprom.h, isr.c, lcd_driver.h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]
2014-12-30 Update README.txt
    Add it to the Part list for de.mouser
2015-01-08 Update README.txt
    Сontains мalid version AVR-Studio and compiller.
2017-06-13 Create ltag_ascetic.c
    Fixed bug when processing the message "start a new game"
    [ltag_ascetic.c]
2018-05-07 fix error in lcd_shield GERBER file
    [lcd_modul_BoardOutline.gbr, lcd_modul_BottomMask.gbr, lcd_modul_TopMask.gbr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]
2018-05-28 Fixed several bugs related to sound playback.
    [ltag_ascetic.c]
2018-05-29 Fix scheme - R13, R16 nominal
    [LTAscet_3_1_matheboard.dsn]
